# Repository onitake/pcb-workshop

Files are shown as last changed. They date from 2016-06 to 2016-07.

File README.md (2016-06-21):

PCB layouting workshop
======================

These are the example files and a short presentation for an
introduction to printed circuit board layouting with KiCad.

The design is loosely based on [Larry Ogrodnek's nametag](http://analogmachines.com/p/nametag/build/),
with some modifications and enhancements.
There's both through-hole and SMD versions.
The THT version is designed for 5mm LEDs, thus making it very
large. A new 3mm version is being worked on.

The software for the microcontroller is in [a separate project](https://github.com/nuess0r/am-nametag).

You can also find an example for a LED dot matrix display tag.
(currently broken, the pinout is wrong)

Description
-----------

The circuit is grouped in 4 parts:
- 5 LED blocks
- Transistor drivers for each block (based on 2N7002 N-FETs)
- ATtiny13 microcontoller
- CR2032 battery

Each block consists of a total of 20 LEDs in parallel, which can be
soldered on as desired.

It should be noted that the CR2032 has a high internal resistance
and can only deliver small currents, up to about 40mA.

The current-limiting resistors for each block should thus be
adjusted accordingly, to prevent brown-out of the MCU.
Note that the transistors also have a relatively high
on resistance.

If a Li-Ion or LiPo battery is used instead of the button
cell, much higher currents are possible.

The parts are fairly standard and can be ordered from any
supplier, such as Farnell, DigiKey, Reichelt, ...

License
-------

This documentation is copyright © 2016 by Chaostreff Basel and
describes Open Hardware and is licensed under the CERN OHL v. 1.2.
Please see the the [LICENSE](LICENSE) file for applicable conditions.

The author's contact information can be found in [AUTHORS](AUTHORS).

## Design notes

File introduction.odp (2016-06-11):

## KiCad

Introduction to Printed Circuit Board design

with KiCad 4.0

CoSin 2016

Gregor Riepl

## About KiCad

- PCB CAD Tool
- Open Source (GPL 3)
- Multiplatform (Windows, OSX, Linux, *BSD, …)
- Started in 1992
- Officially endorsed by CERN
- Many professional features
- Suitable for very simple and very complex projects

## Overview

- kicad
- eeschema
- cvpcb
- pcbnew
- gerbview
- pcb calculator
- part editor
- footprint editor

## kicad

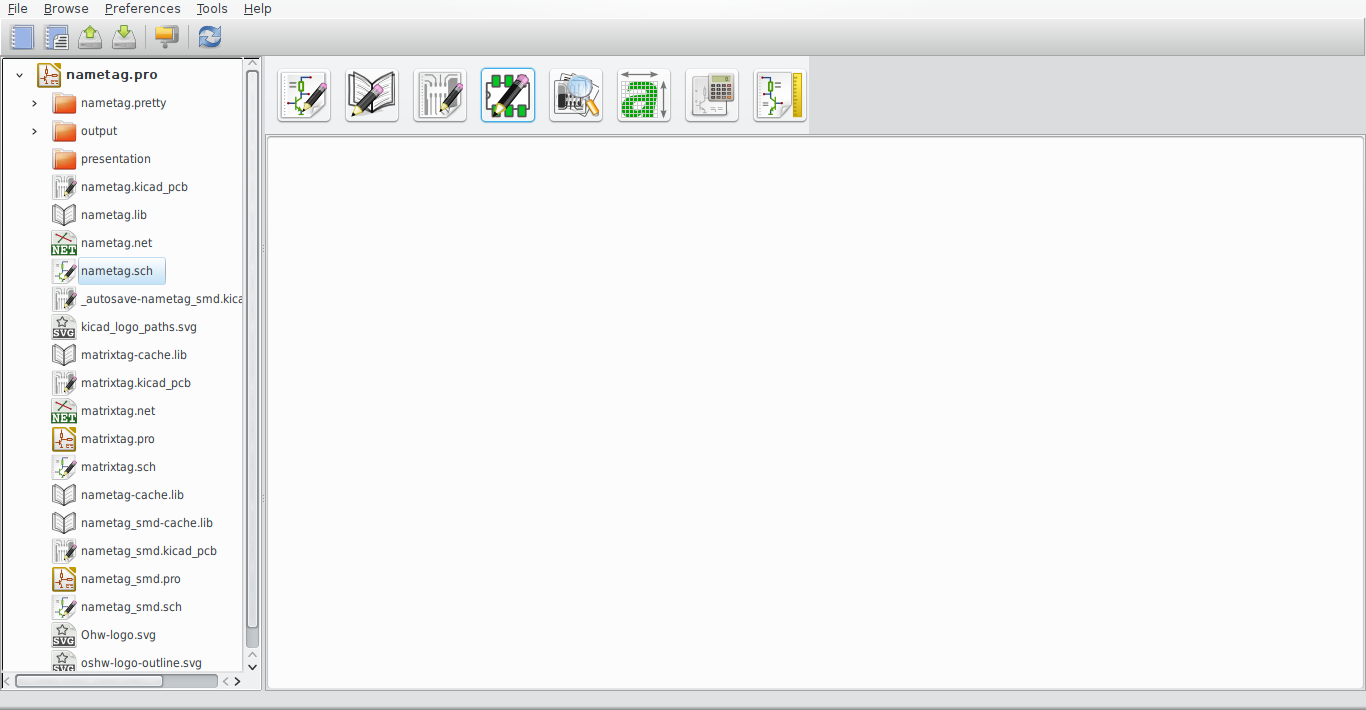
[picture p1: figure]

## eeschema

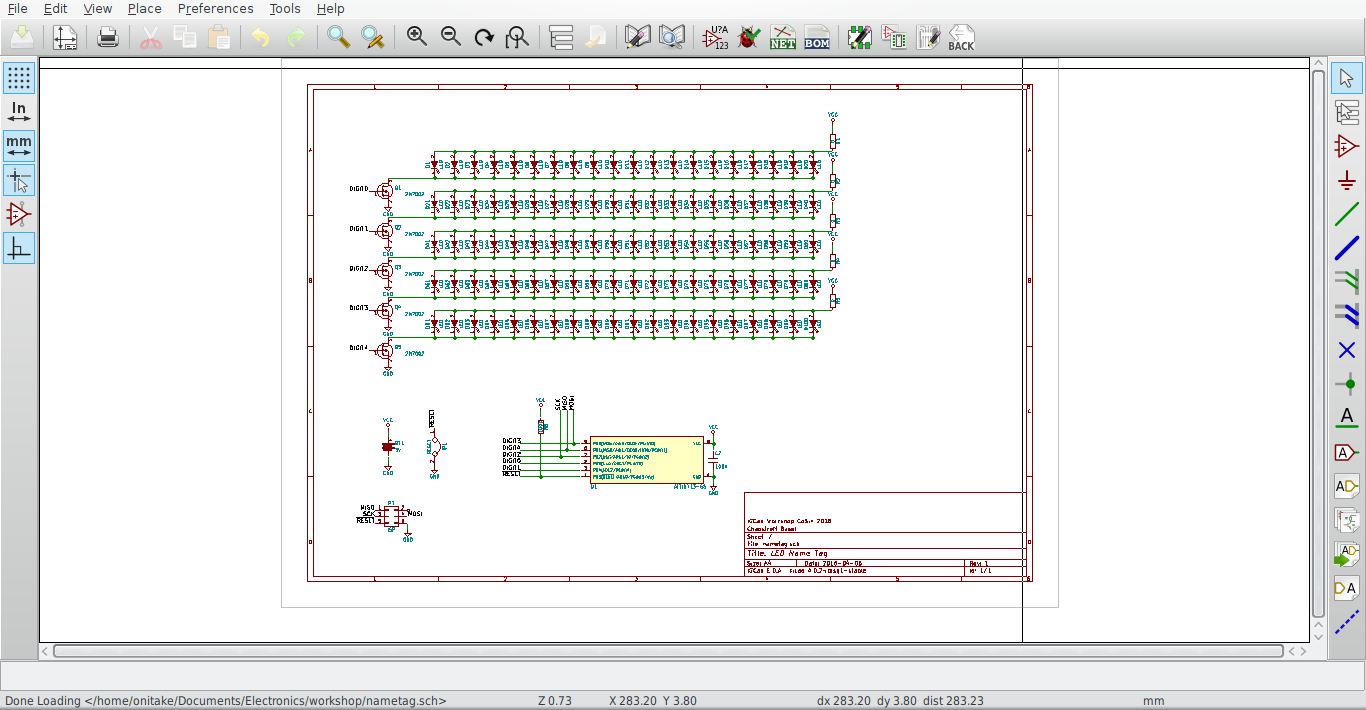
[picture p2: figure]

## cvpcb

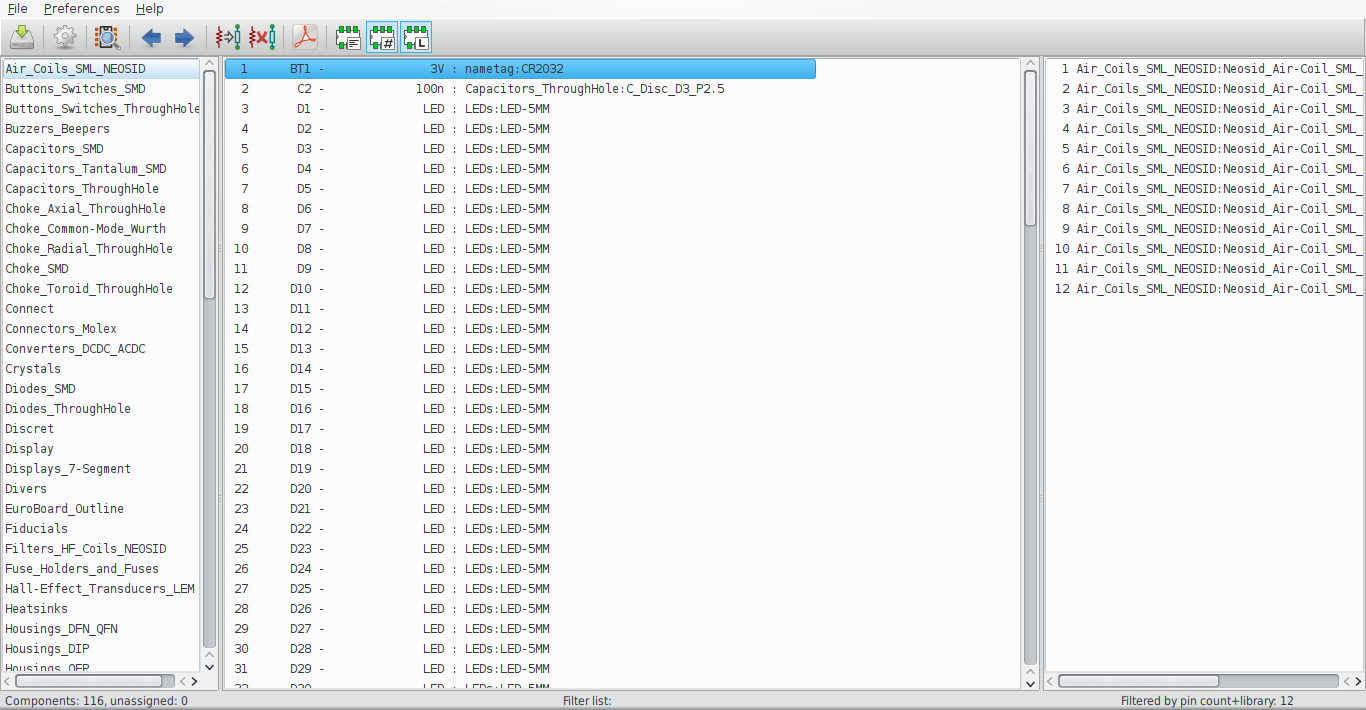
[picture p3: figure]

## pcbnew

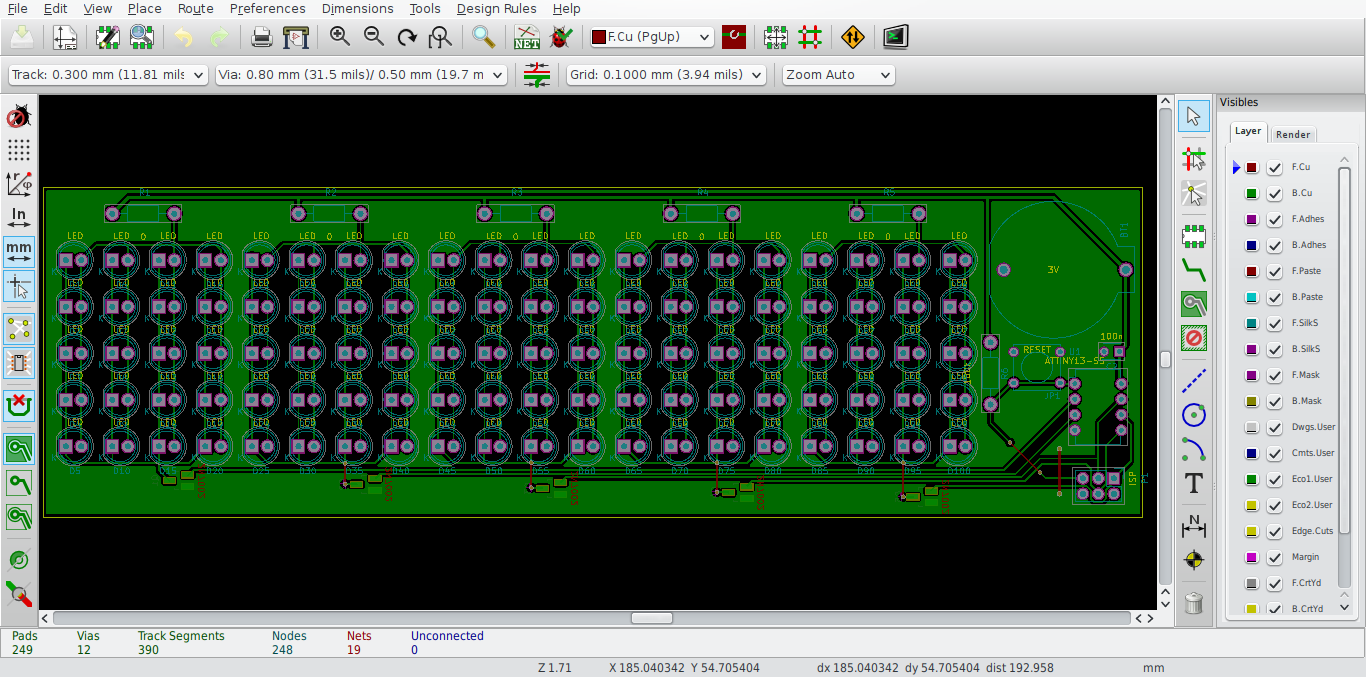
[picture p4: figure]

## gerbview

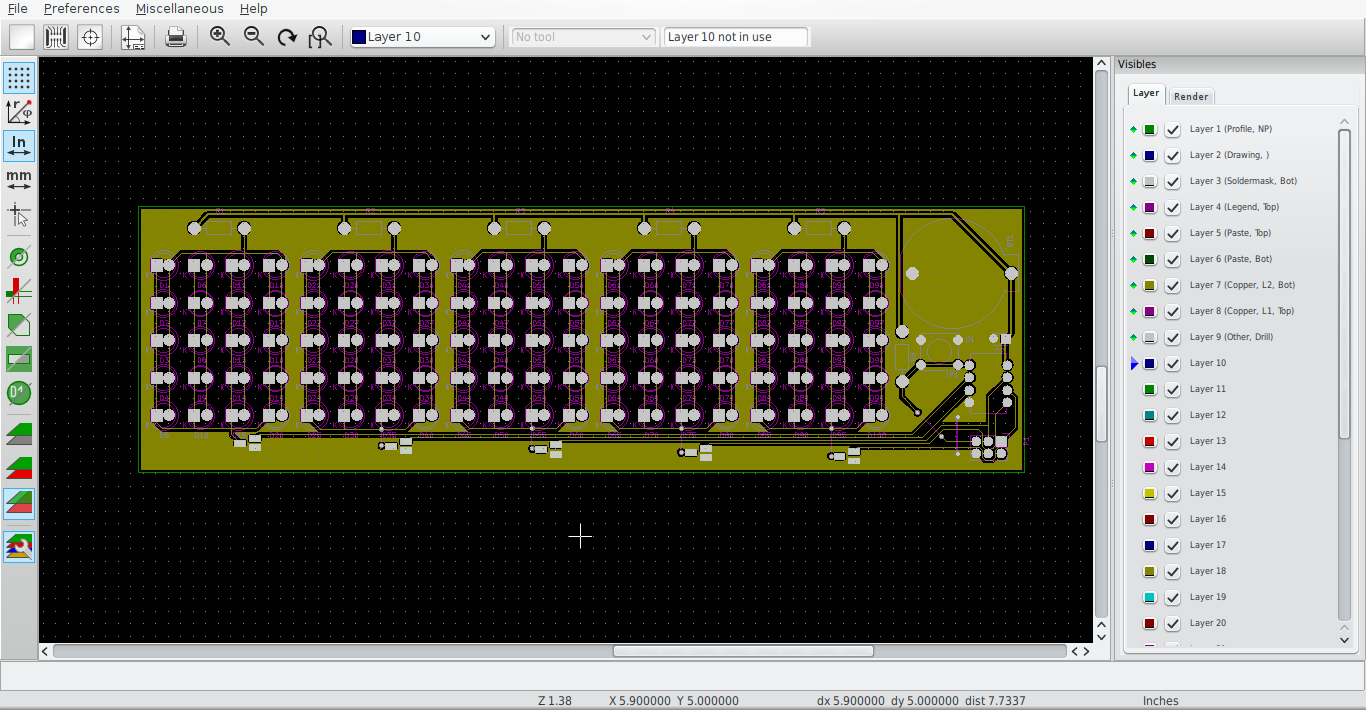
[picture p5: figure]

## part editor

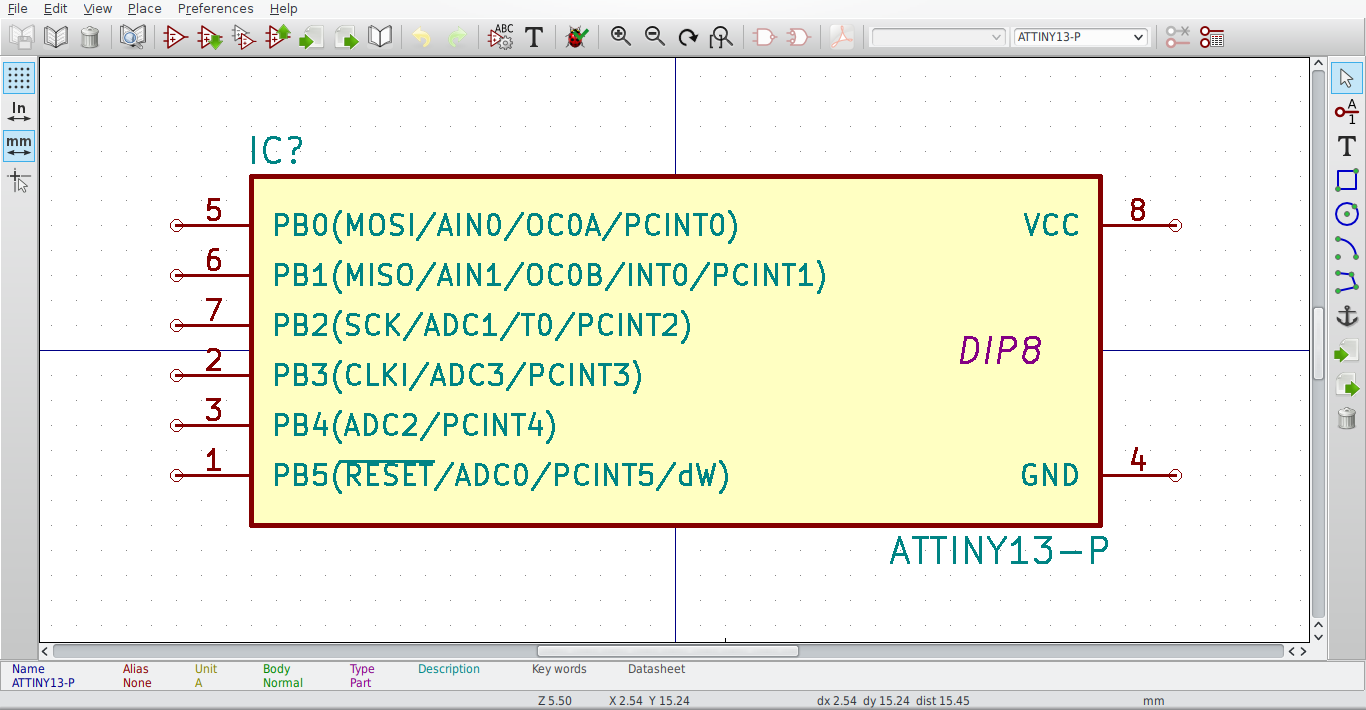
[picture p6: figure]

## footprint editor

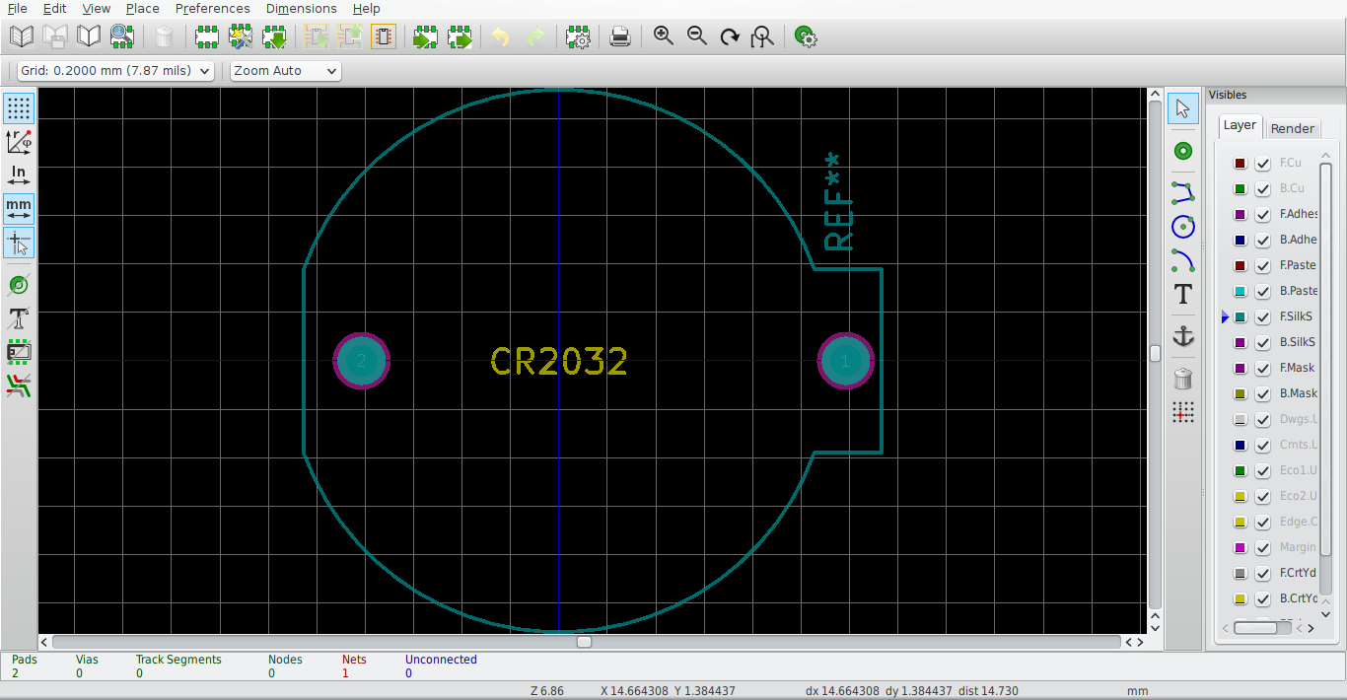
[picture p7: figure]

## Workflow

- Schema design
- Footprint assignment
- Netlist export / import
- PCB design
- Gerber / PDF export
- Verification
- Production

## Schema design

- Layout decision
- Part sourcing
- Part design / editing / library import
- Part placement
- Tracing / labeling
- Fine tuning
- Annotation
- ERC

## Parts

- KiCad has a large part library
- kicadlib.org has many more
- Creating custom parts is easy

## Netlists

- netlists = interface between eeschema and pcbnew
- Export after schema is complete
- Then import into pcbnew
- Backward annotation is not possible

## PCB design

- Design rules / Net classes
- Layout decision / edge cuts
- Part placement
- Power / ground planes
- Routing
- DRC

## Output

- Use Gerber for CAM
- Use PDF for DIY
- Each layer is a separate file
- Gerber layers can be checked in gerbview
- PDF export best mirrored, better exposure (focus)

## Questions?

- Answers!

## More

- http://kicad-pcb.org
- http://press.cern/press-releases/2011/07/cern-launches-open-hardware-initiative
- http://www.kicadlib.org/
- https://github.com/onitake/pcb-workshop

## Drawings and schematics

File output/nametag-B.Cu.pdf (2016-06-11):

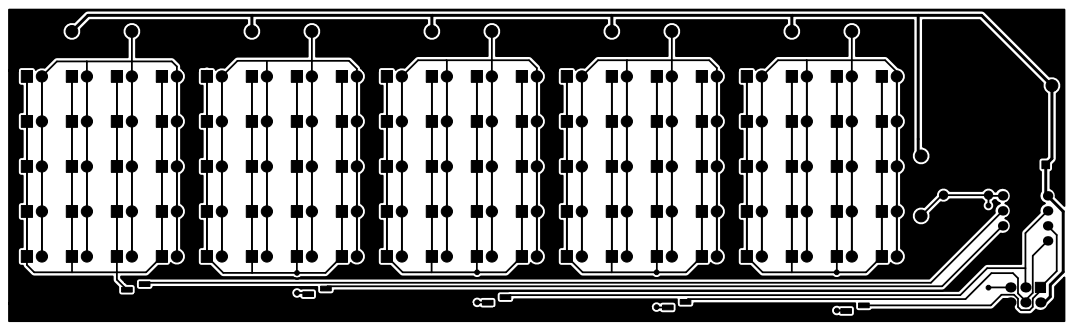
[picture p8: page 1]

File: nametag.kicad_pcb Sheet: Chaostreff Basel KiCad Workshop CoSin 2016

Id: 1/1 Title: LED Name Tag

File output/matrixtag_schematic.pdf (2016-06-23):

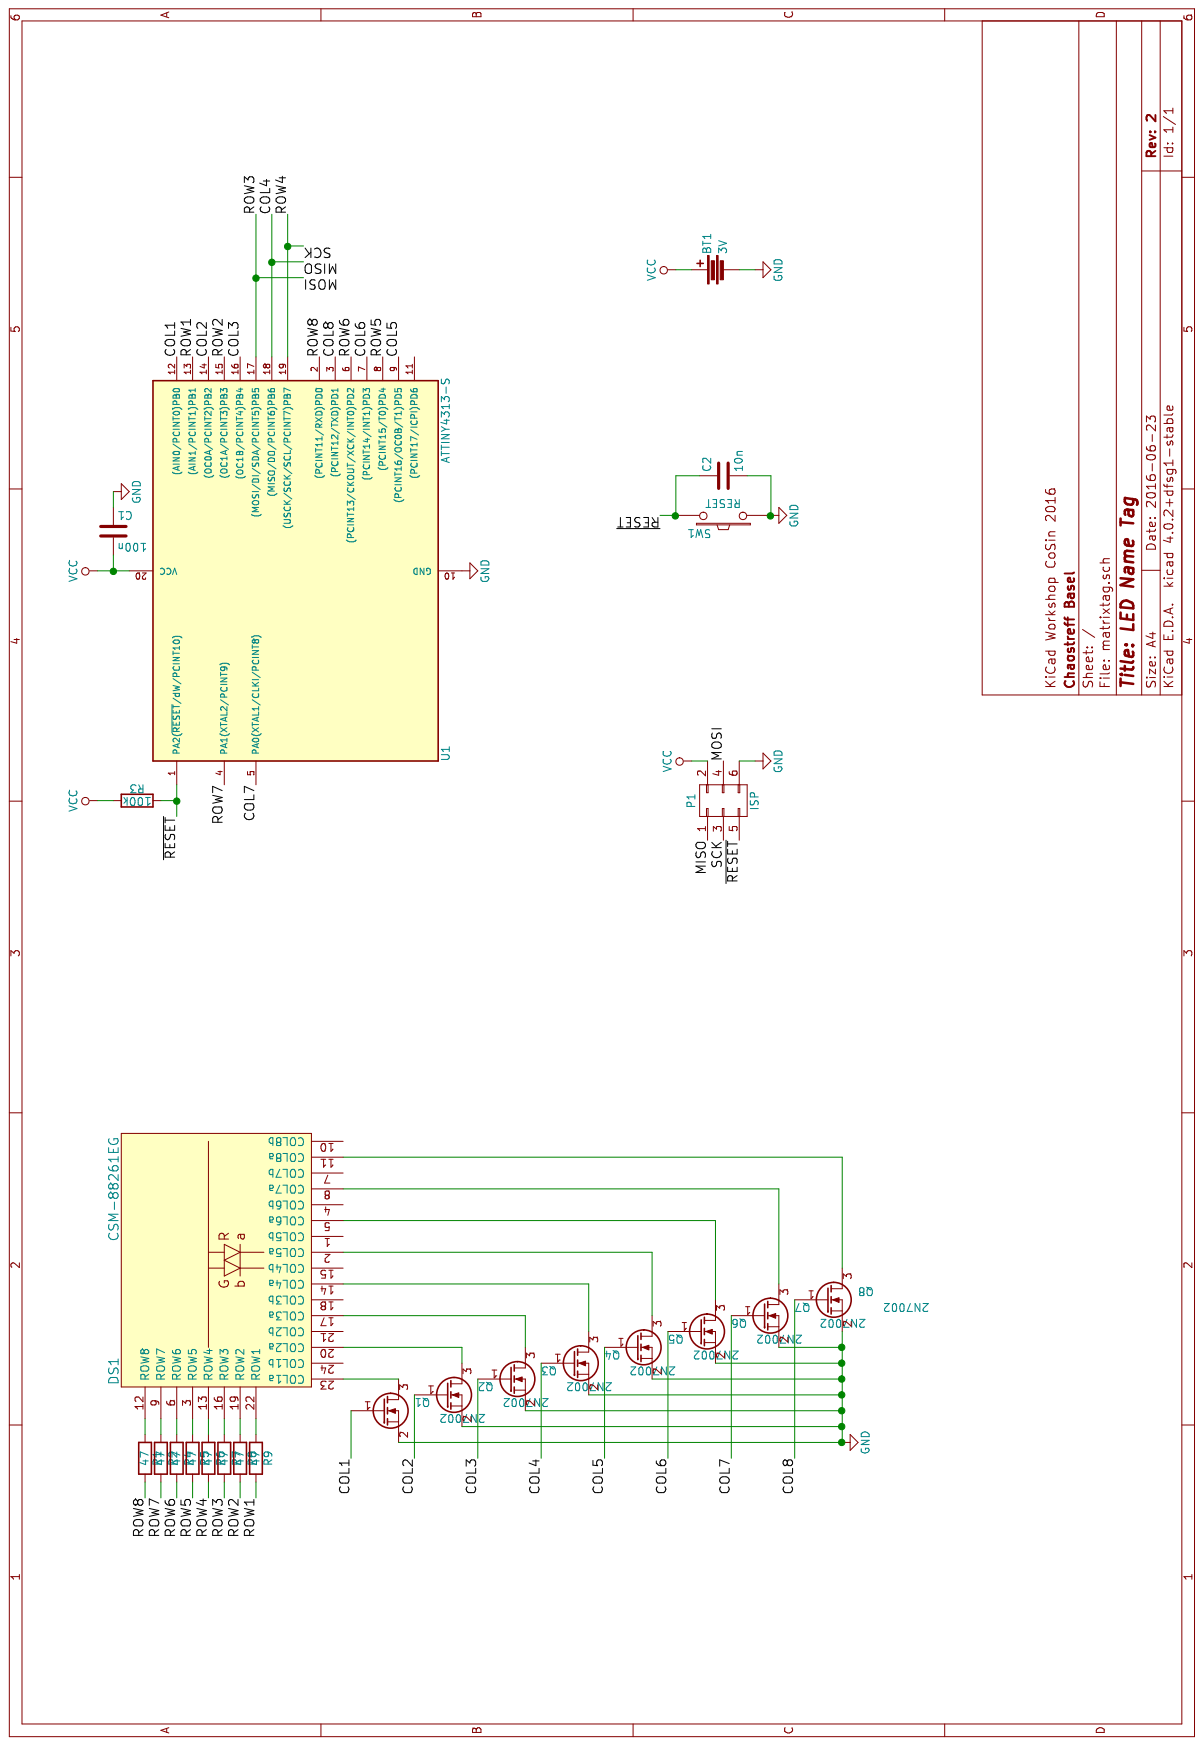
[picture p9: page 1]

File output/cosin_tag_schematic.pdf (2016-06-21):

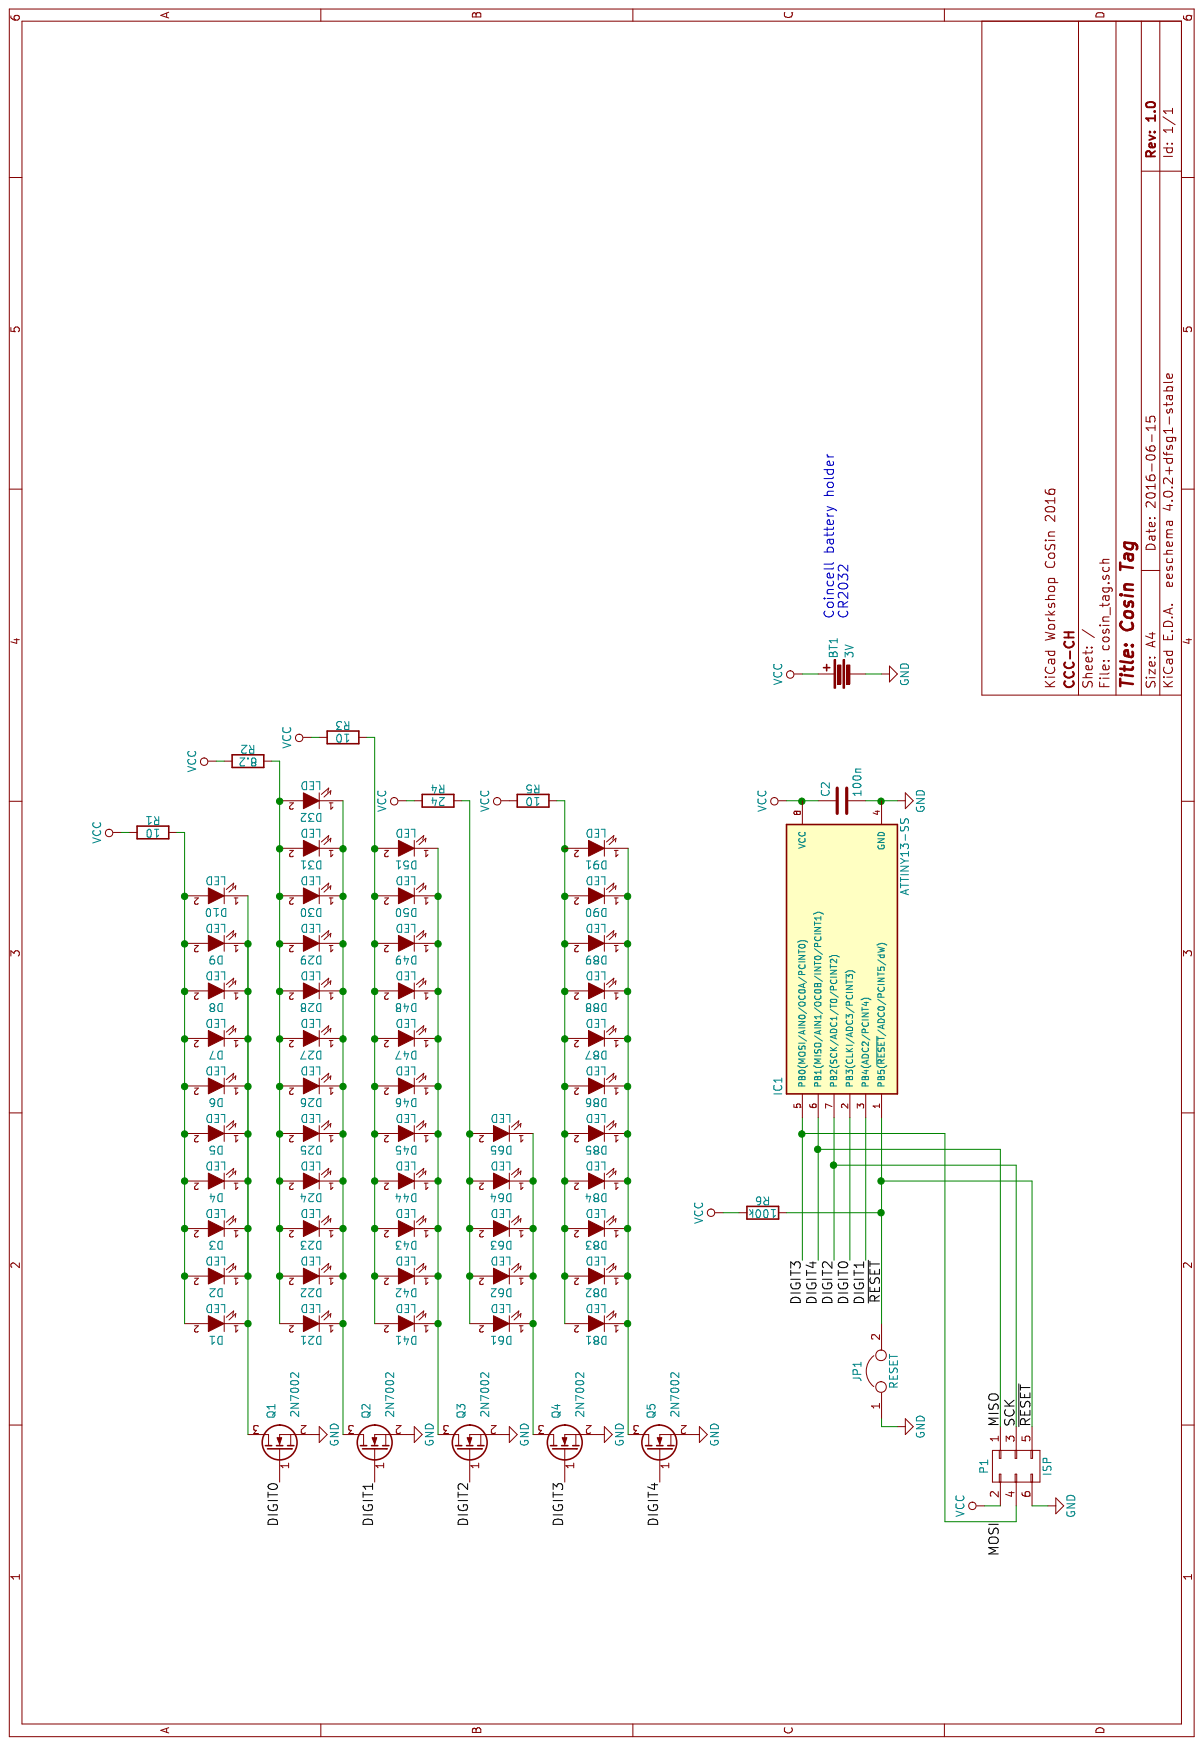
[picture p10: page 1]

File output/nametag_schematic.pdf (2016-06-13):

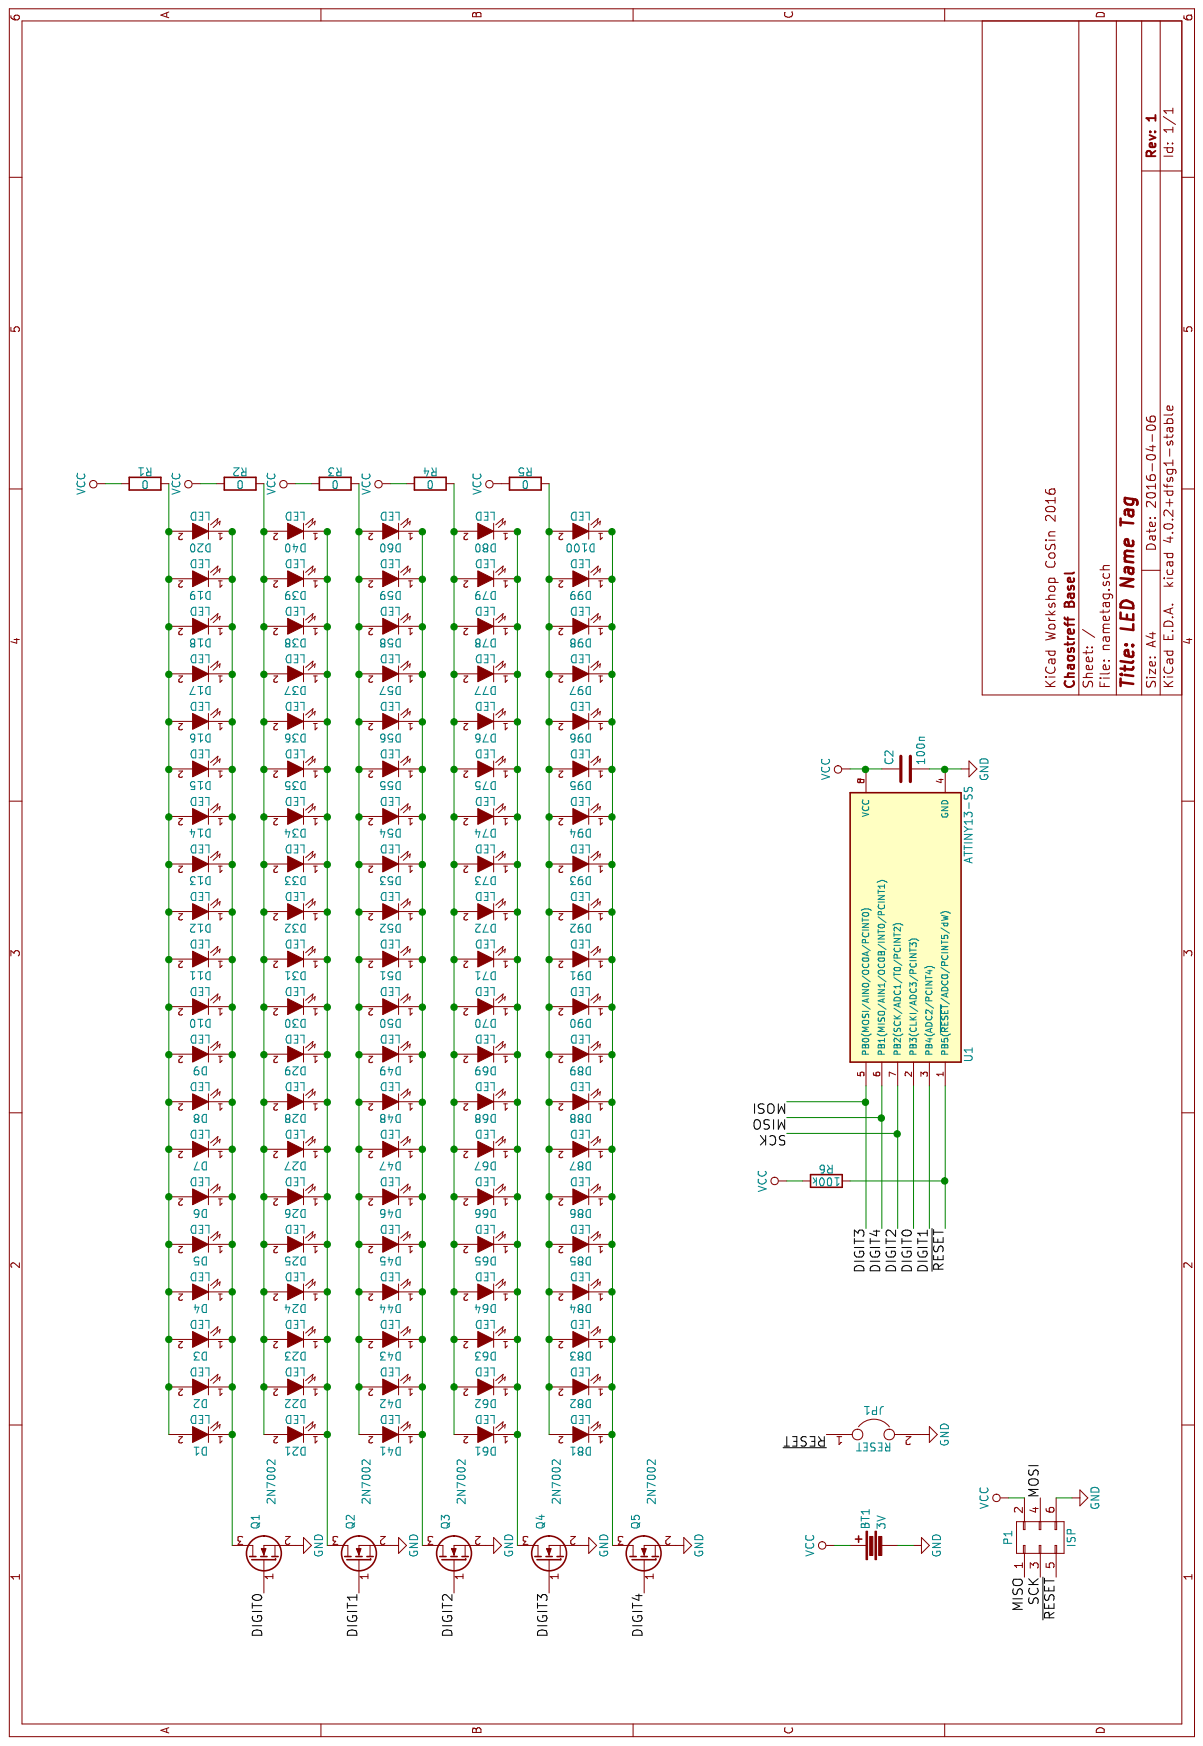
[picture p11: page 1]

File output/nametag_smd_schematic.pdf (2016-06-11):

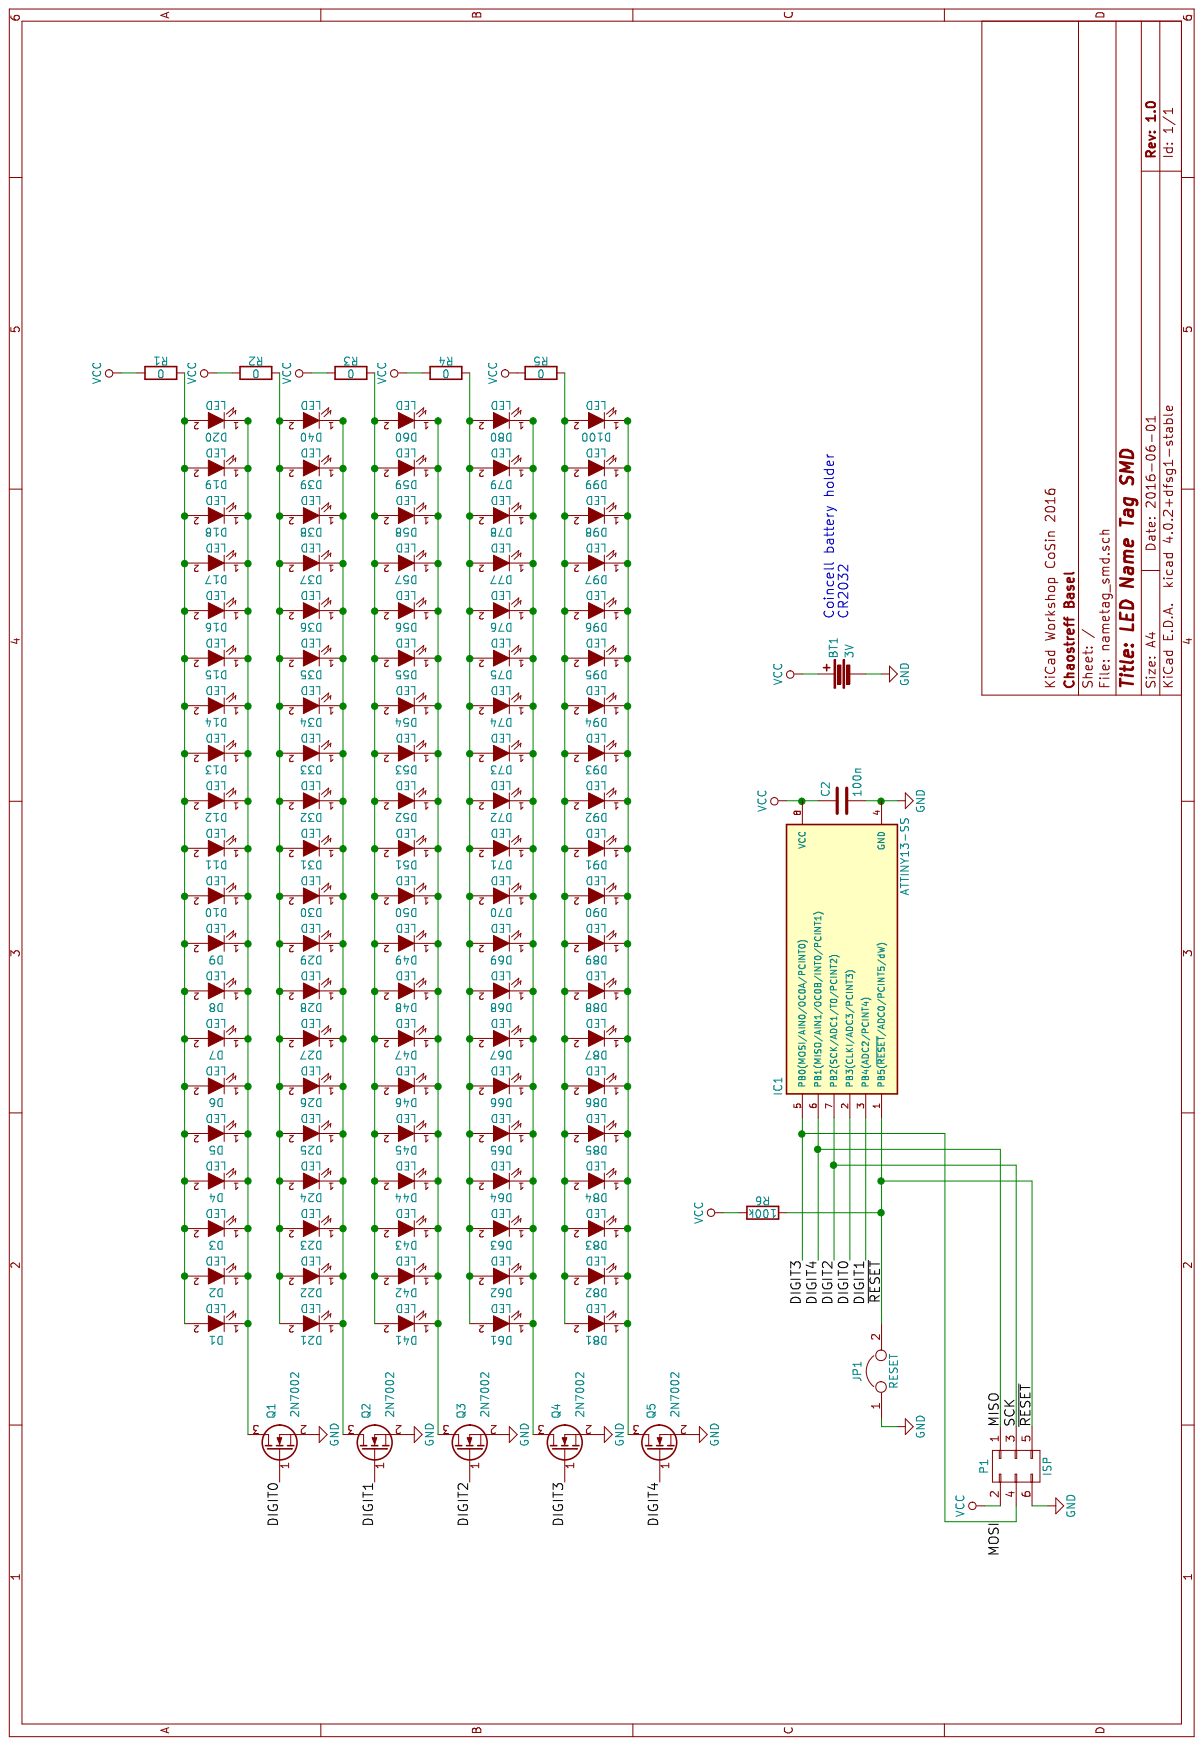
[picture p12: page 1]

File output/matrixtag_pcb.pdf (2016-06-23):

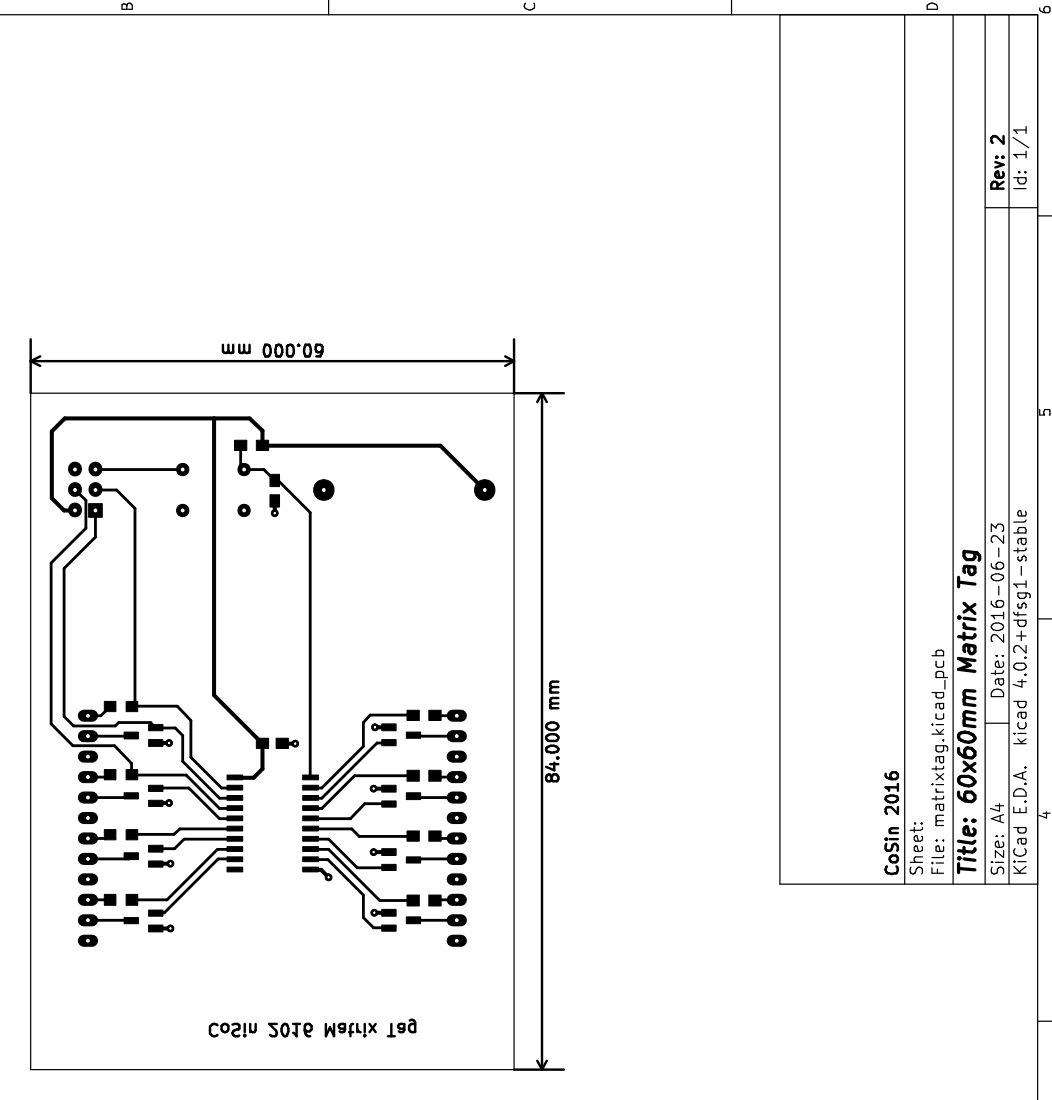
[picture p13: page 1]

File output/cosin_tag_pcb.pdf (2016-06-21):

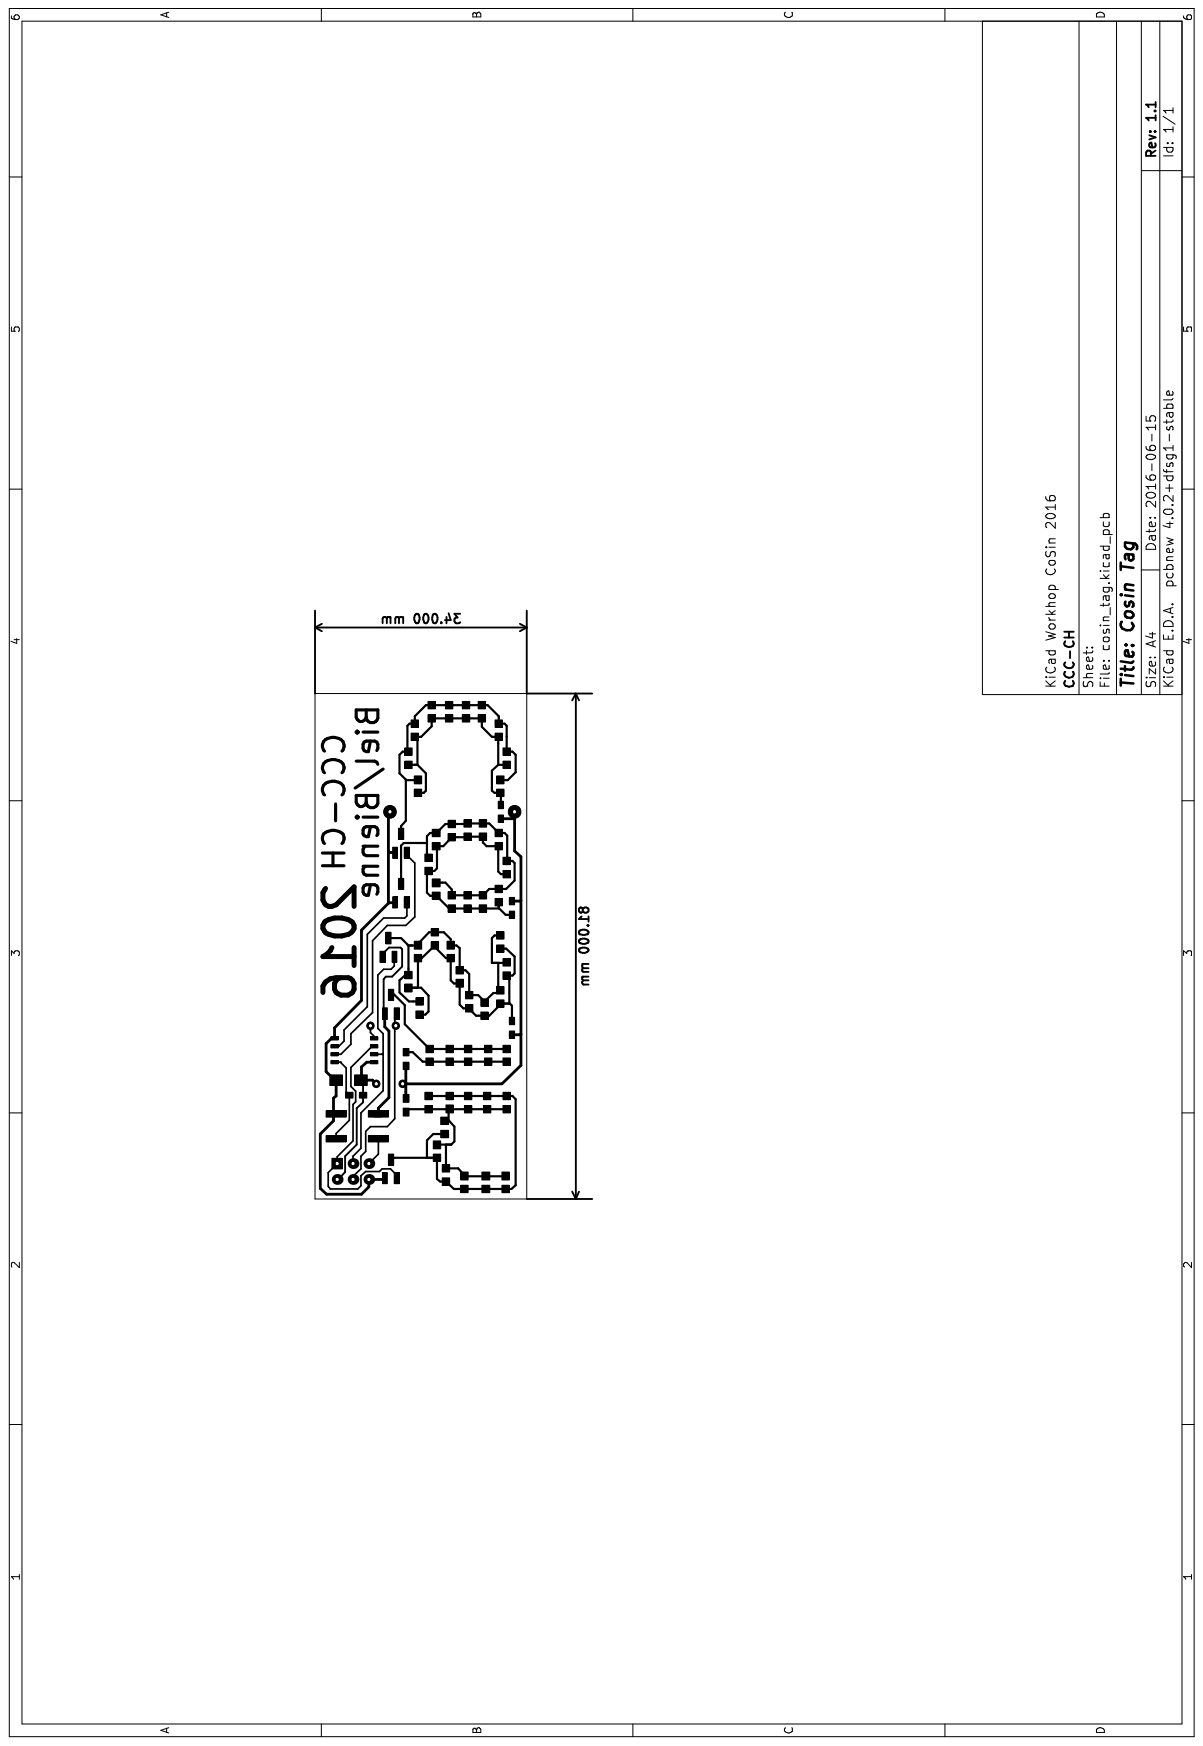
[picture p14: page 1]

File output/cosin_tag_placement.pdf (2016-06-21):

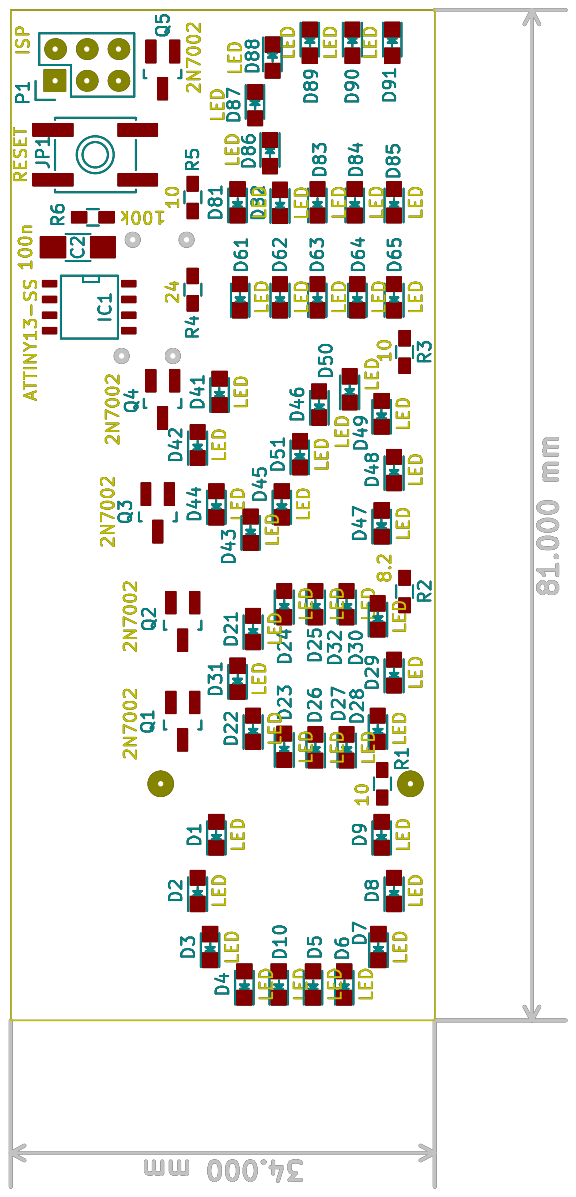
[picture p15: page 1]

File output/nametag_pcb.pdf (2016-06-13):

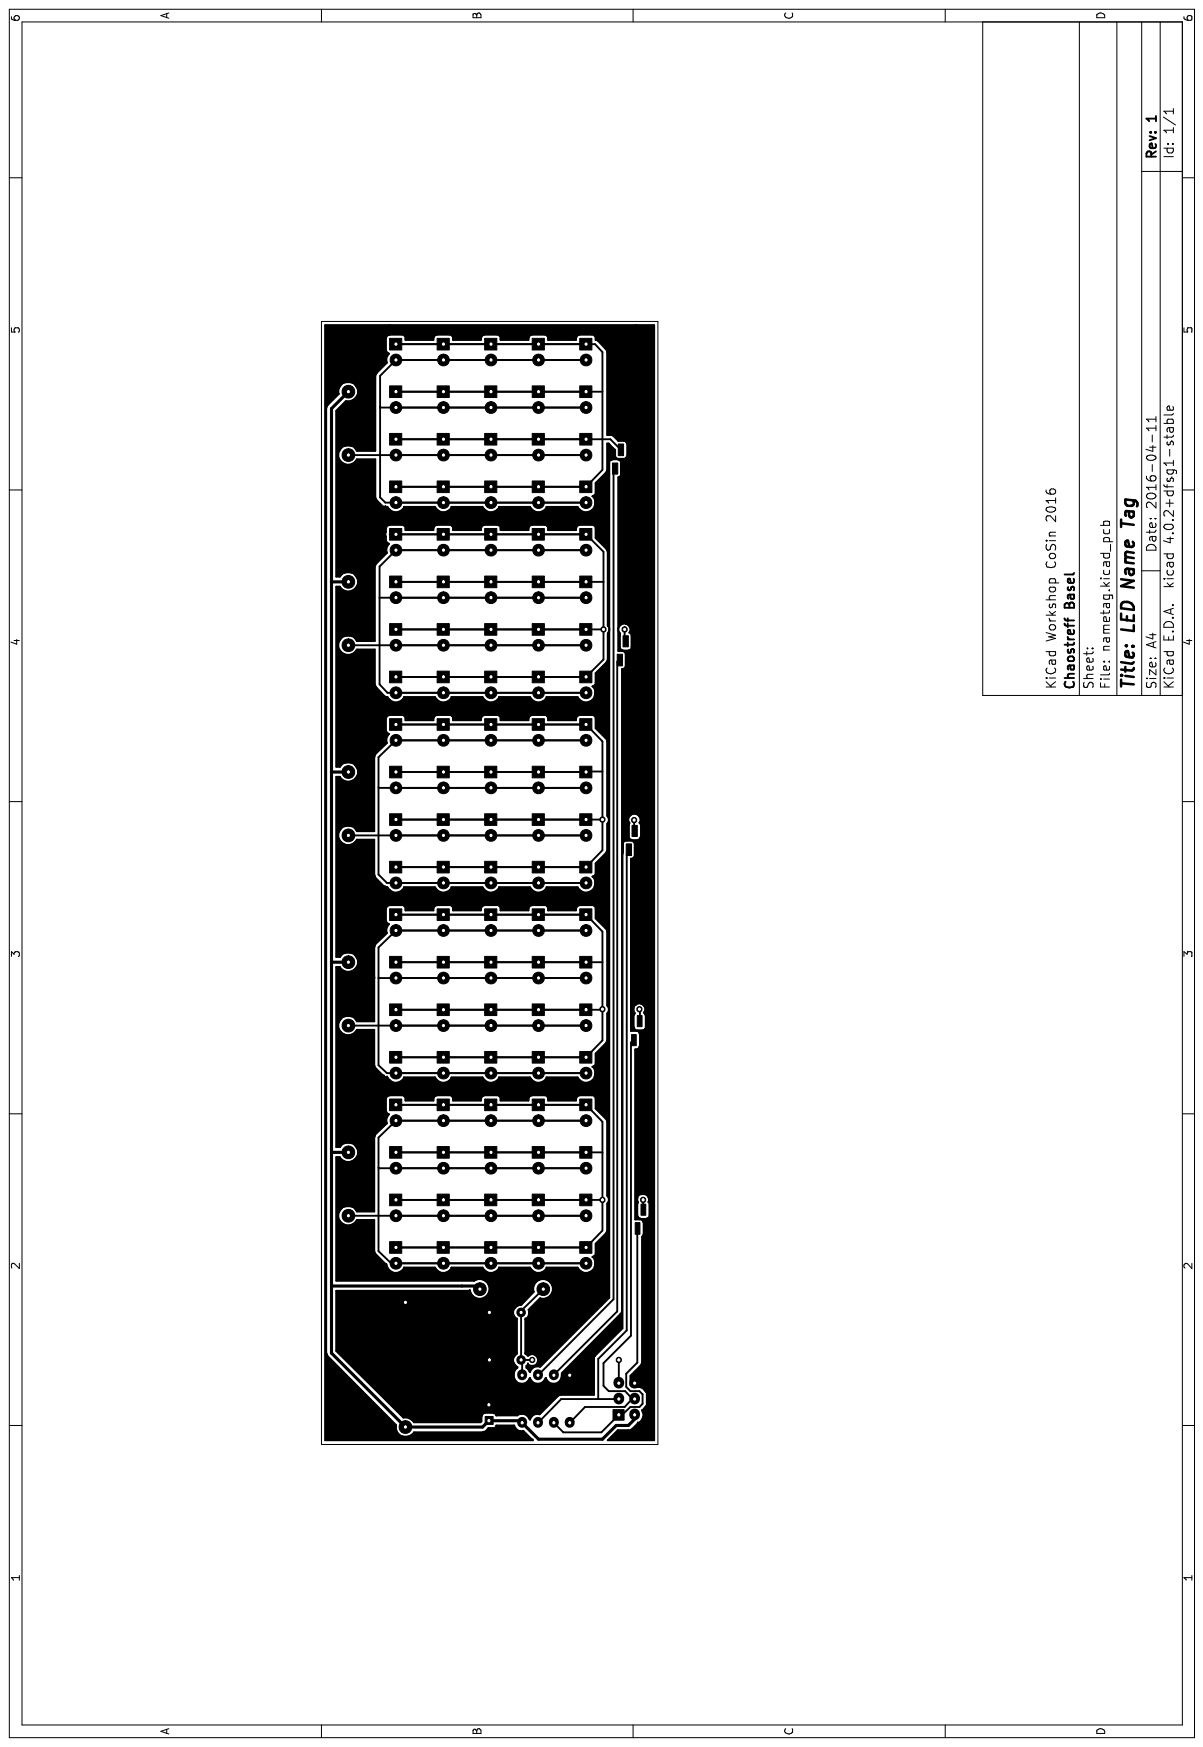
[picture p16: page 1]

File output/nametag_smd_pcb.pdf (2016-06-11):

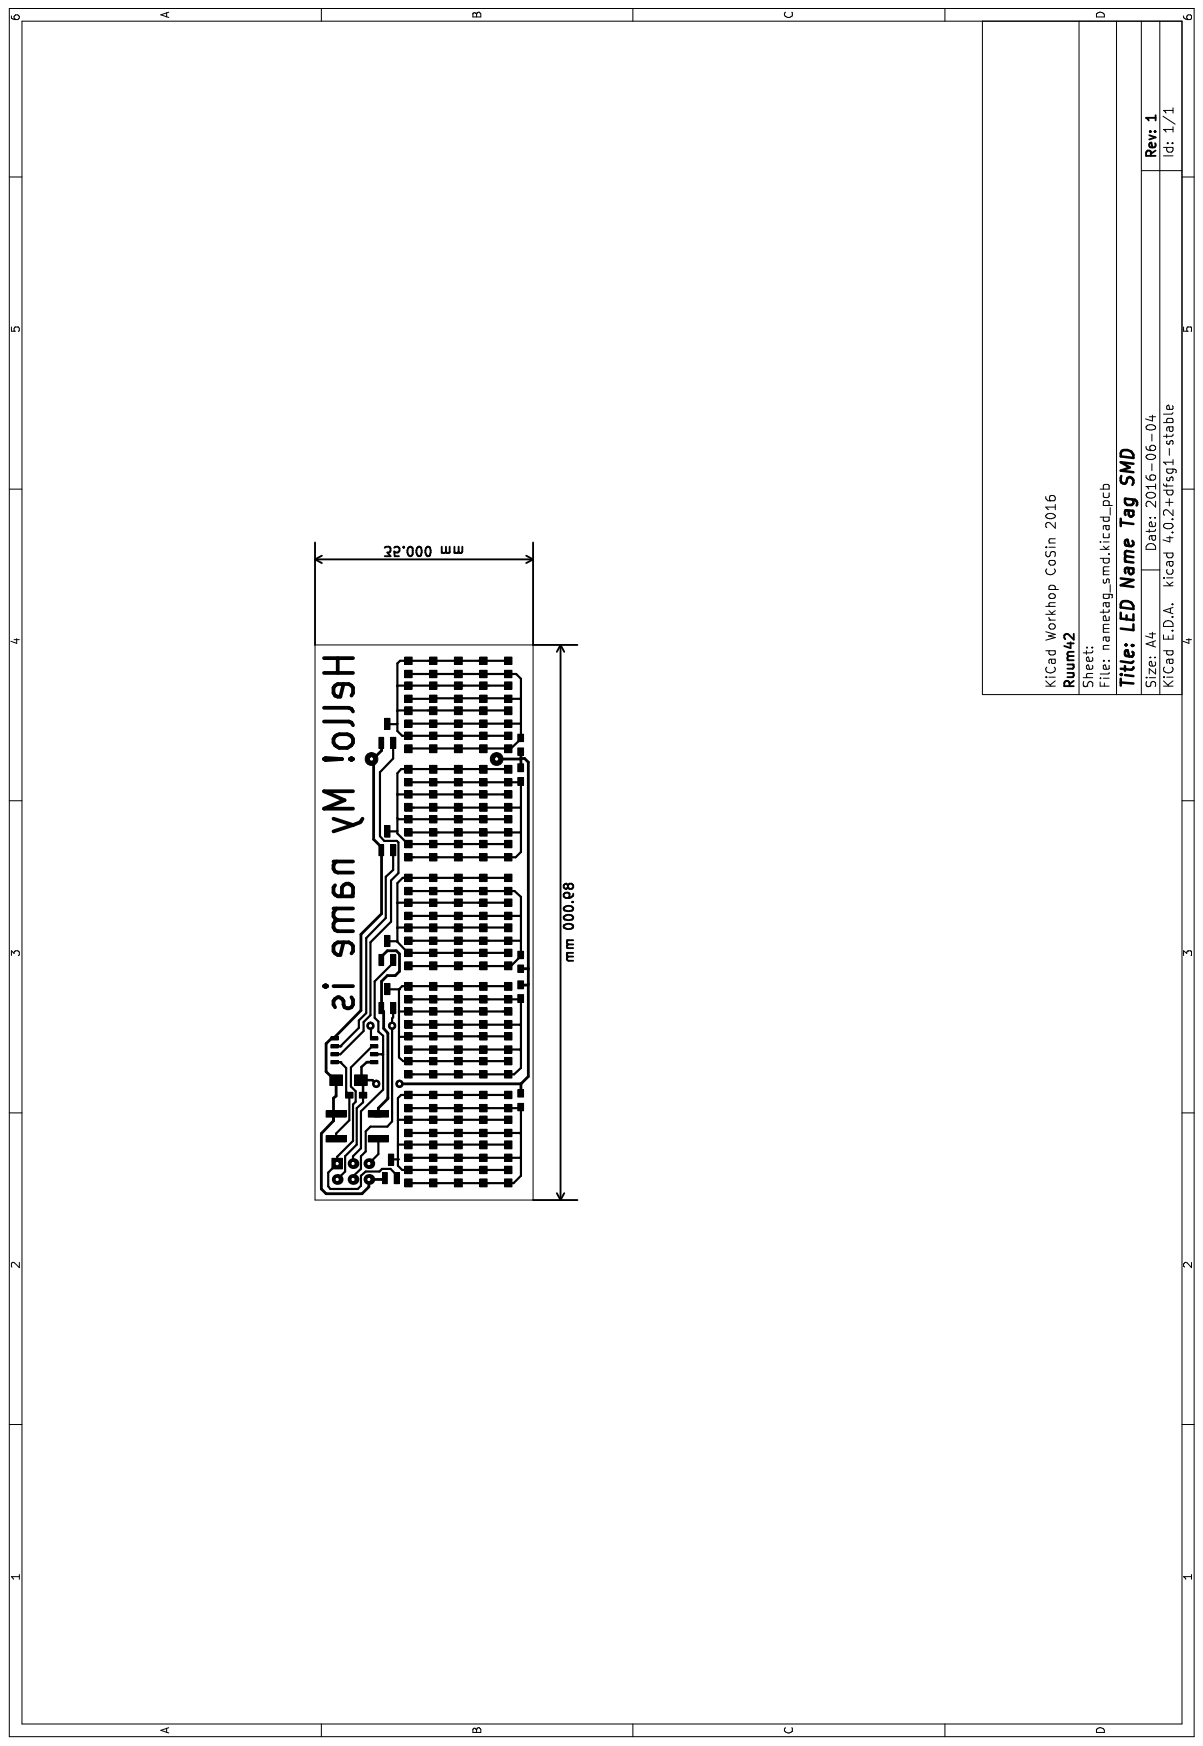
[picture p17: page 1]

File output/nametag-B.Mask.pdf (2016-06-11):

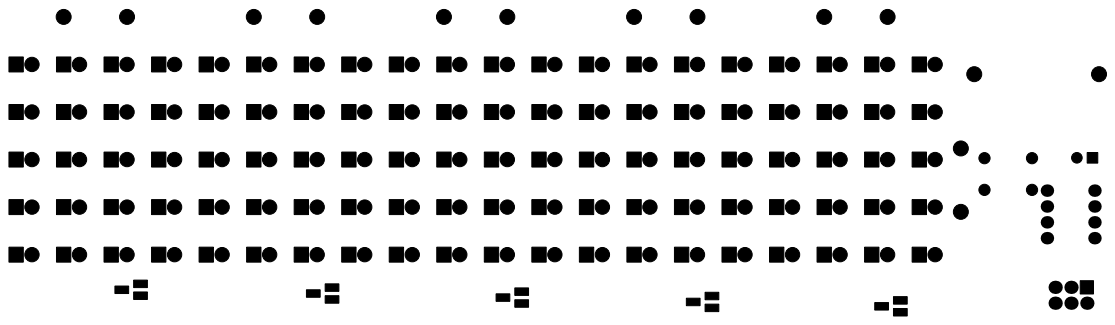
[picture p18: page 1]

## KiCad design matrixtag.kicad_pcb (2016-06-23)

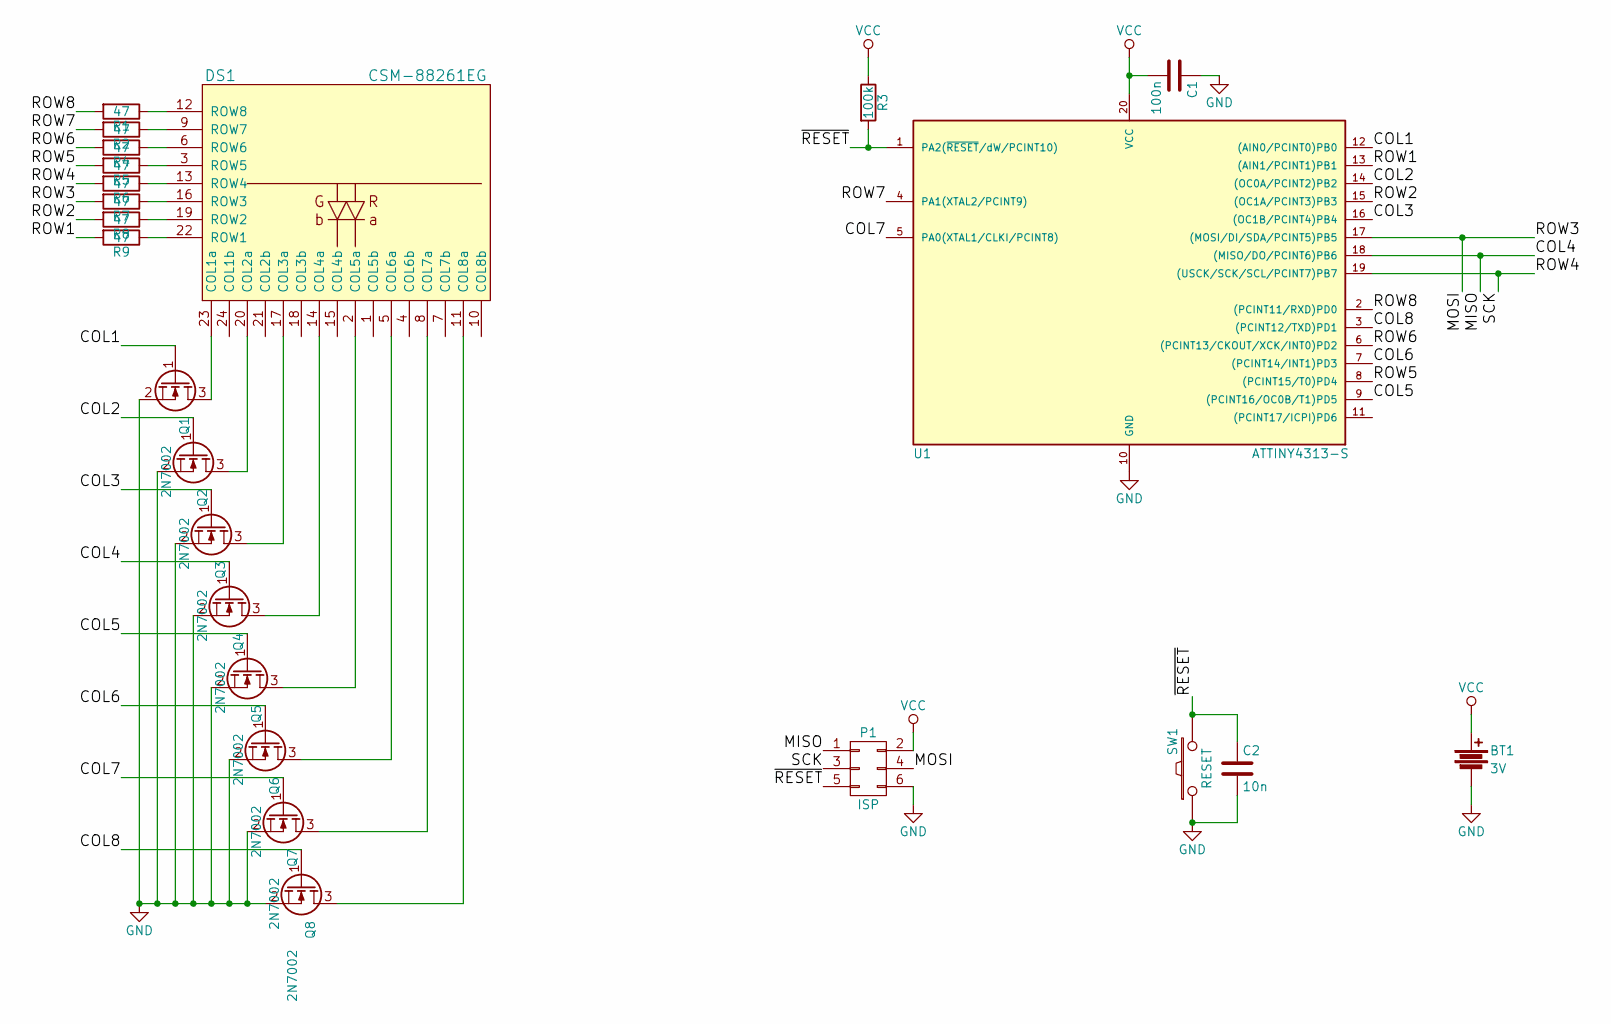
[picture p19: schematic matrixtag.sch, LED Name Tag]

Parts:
BT1: 3V; CR2032
C1: 100n; C_0805_HandSoldering
C2: 10n; C_0805_HandSoldering
DS1: CSM-88261EG; CSM-88261
P1: ISP; Pin_Header_Straight_2x03
Q1, Q2, Q3, Q4, Q5, Q6, Q7, Q8: 2N7002; SOT-23_Handsoldering
R1, R2, R4, R5, R6, R7, R8, R9: 47; R_0805_HandSoldering
R3: 100k; R_0805_HandSoldering
SW1: RESET; SW_PUSH_SMALL
U1: ATTINY4313-S; SOIC-20_7.5x12.8mm_Pitch1.27mm

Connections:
/COL1: Q1.1 (G), U1.12 ((AIN0/PCINT0)PB0)
/COL2: Q2.1 (G), U1.14 ((OC0A/PCINT2)PB2)
/COL3: Q3.1 (G), U1.16 ((OC1B/PCINT4)PB4)
/COL4: P1.1, Q4.1 (G), U1.18 ((MISO/DO/PCINT6)PB6)
/COL5: Q5.1 (G), U1.9 ((PCINT16/OC0B/T1)PD5)
/COL6: Q6.1 (G), U1.7 ((PCINT14/INT1)PD3)
/COL7: Q7.1 (G), U1.5 (PA0(XTAL1/CLKI/PCINT8))
/COL8: Q8.1 (G), U1.3 ((PCINT12/TXD)PD1)
/MOSI: P1.4, R7.2, U1.17 ((MOSI/DI/SDA/PCINT5)PB5)
/ROW1: R9.2, U1.13 ((AIN1/PCINT1)PB1)
/ROW2: R8.2, U1.15 ((OC1A/PCINT3)PB3)
/ROW4: P1.3, R6.2, U1.19 ((USCK/SCK/SCL/PCINT7)PB7)
/ROW5: R5.2, U1.8 ((PCINT15/T0)PD4)
/ROW6: R4.2, U1.6 ((PCINT13/CKOUT/XCK/INT0)PD2)
/ROW7: R2.2, U1.4 (PA1(XTAL2/PCINT9))
/ROW8: R1.2, U1.2 ((PCINT11/RXD)PD0)
/~RESET: C2.1, P1.5, R3.2, SW1.2, U1.1 (PA2(~RESET~/dW/PCINT10))
GND: BT1.2, C1.1, C2.2, P1.6, Q1.2 (S), Q2.2 (S), Q3.2 (S), Q4.2 (S), Q5.2 (S), Q6.2 (S), Q7.2 (S), Q8.2 (S), SW1.1, U1.10 (GND)
unnamed: DS1.2 (COL5a), Q5.3 (D)
unnamed: DS1.3 (ROW5), R5.1
unnamed: DS1.5 (COL6a), Q6.3 (D)
unnamed: DS1.6 (ROW6), R4.1
unnamed: DS1.8 (COL7a), Q7.3 (D)
unnamed: DS1.9 (ROW7), R2.1
unnamed: DS1.11 (COL8a), Q8.3 (D)
unnamed: DS1.12 (ROW8), R1.1
unnamed: DS1.13 (ROW4), R6.1
unnamed: DS1.14 (COL4a), Q4.3 (D)
unnamed: DS1.16 (ROW3), R7.1
unnamed: DS1.17 (COL3a), Q3.3 (D)
unnamed: DS1.19 (ROW2), R8.1
unnamed: DS1.20 (COL2a), Q2.3 (D)
unnamed: DS1.22 (ROW1), R9.1
unnamed: DS1.23 (COL1a), Q1.3 (D)
VCC: BT1.1, C1.2, P1.2, R3.1, U1.20 (VCC)

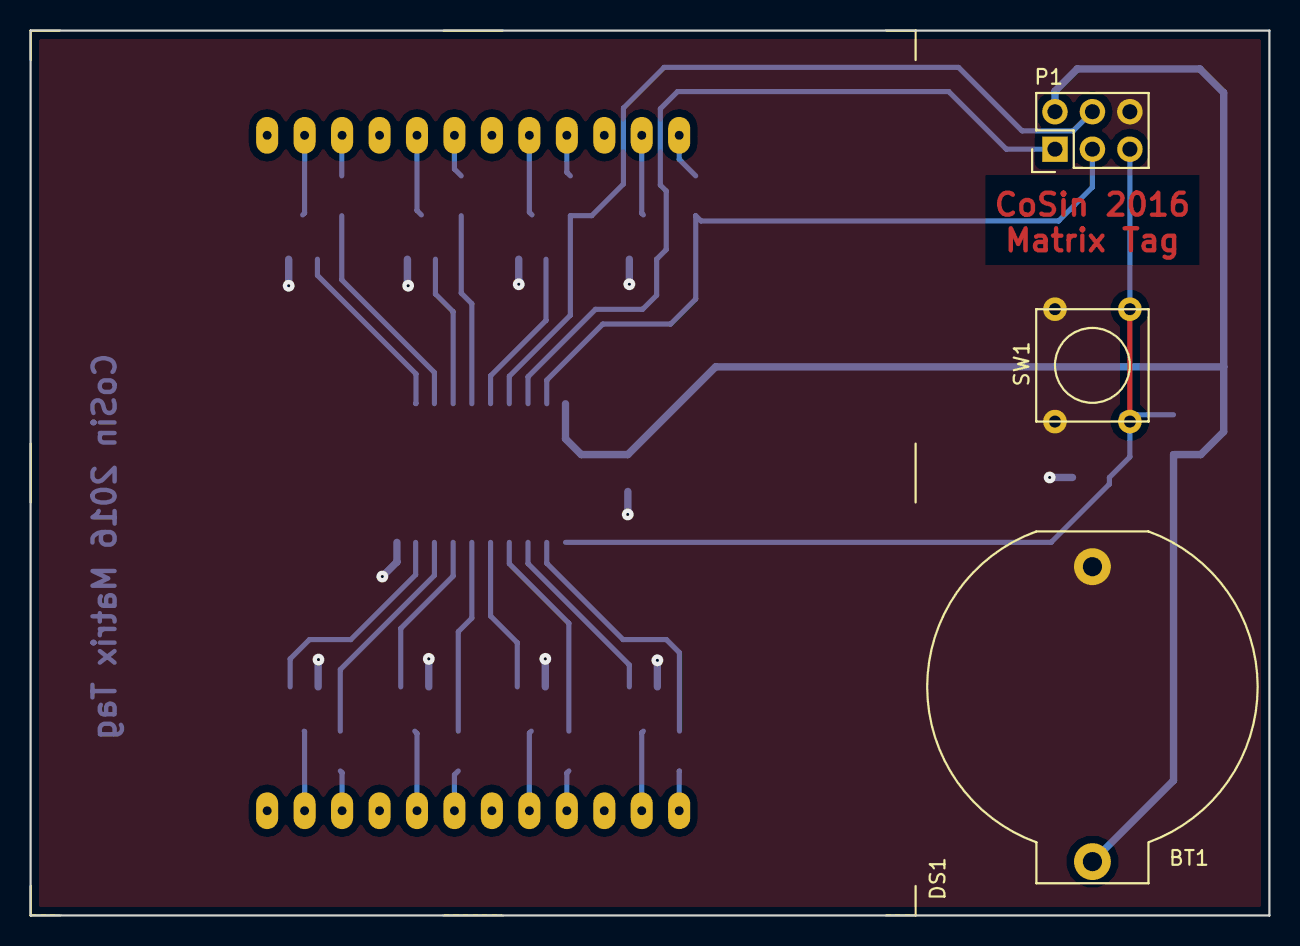
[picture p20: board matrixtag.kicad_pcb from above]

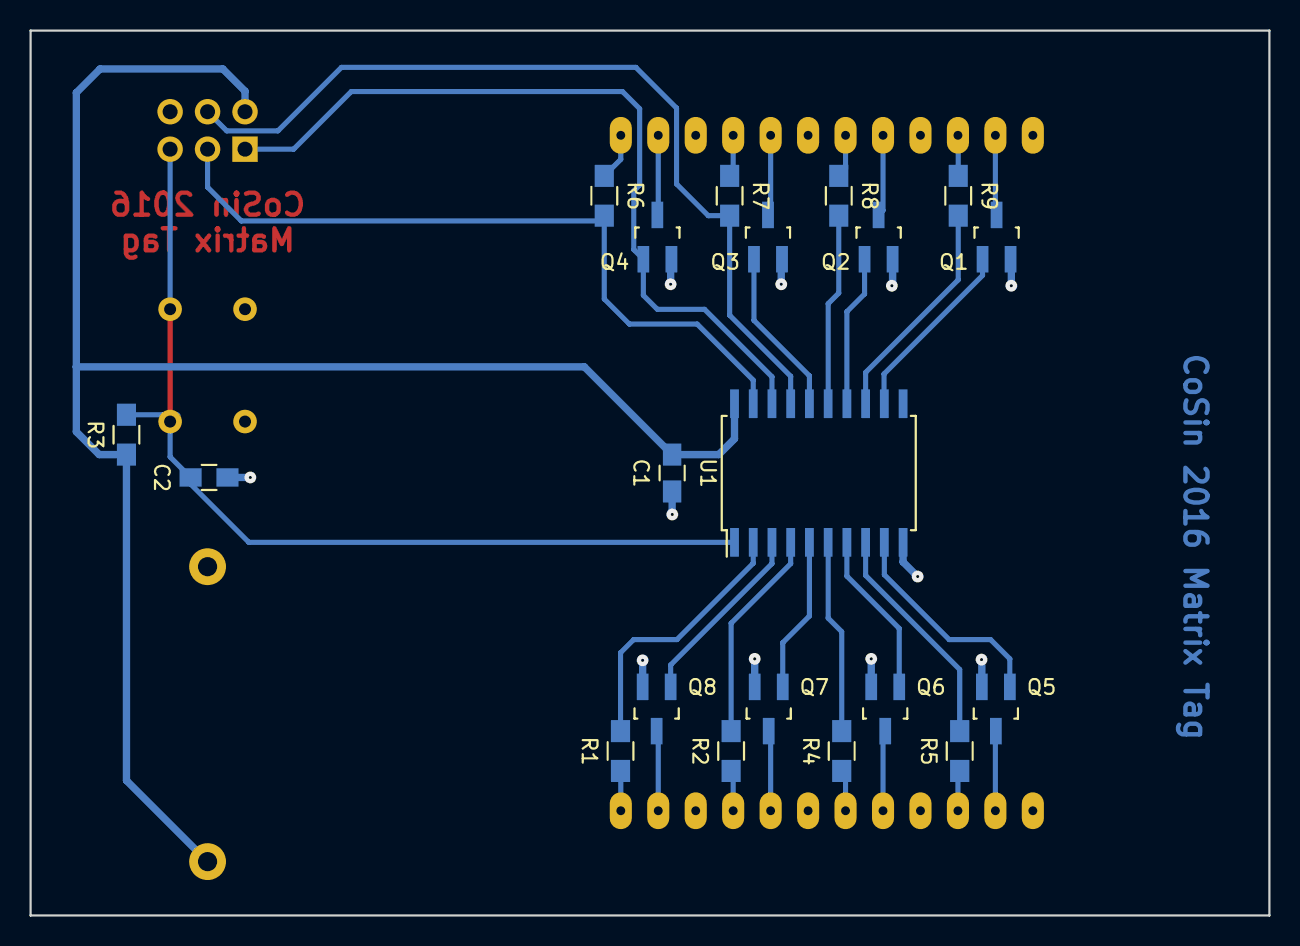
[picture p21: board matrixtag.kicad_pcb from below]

Board: 2 copper layers, 84.0 x 60.0 mm, 24 parts (20 on the bottom side), 35 nets.

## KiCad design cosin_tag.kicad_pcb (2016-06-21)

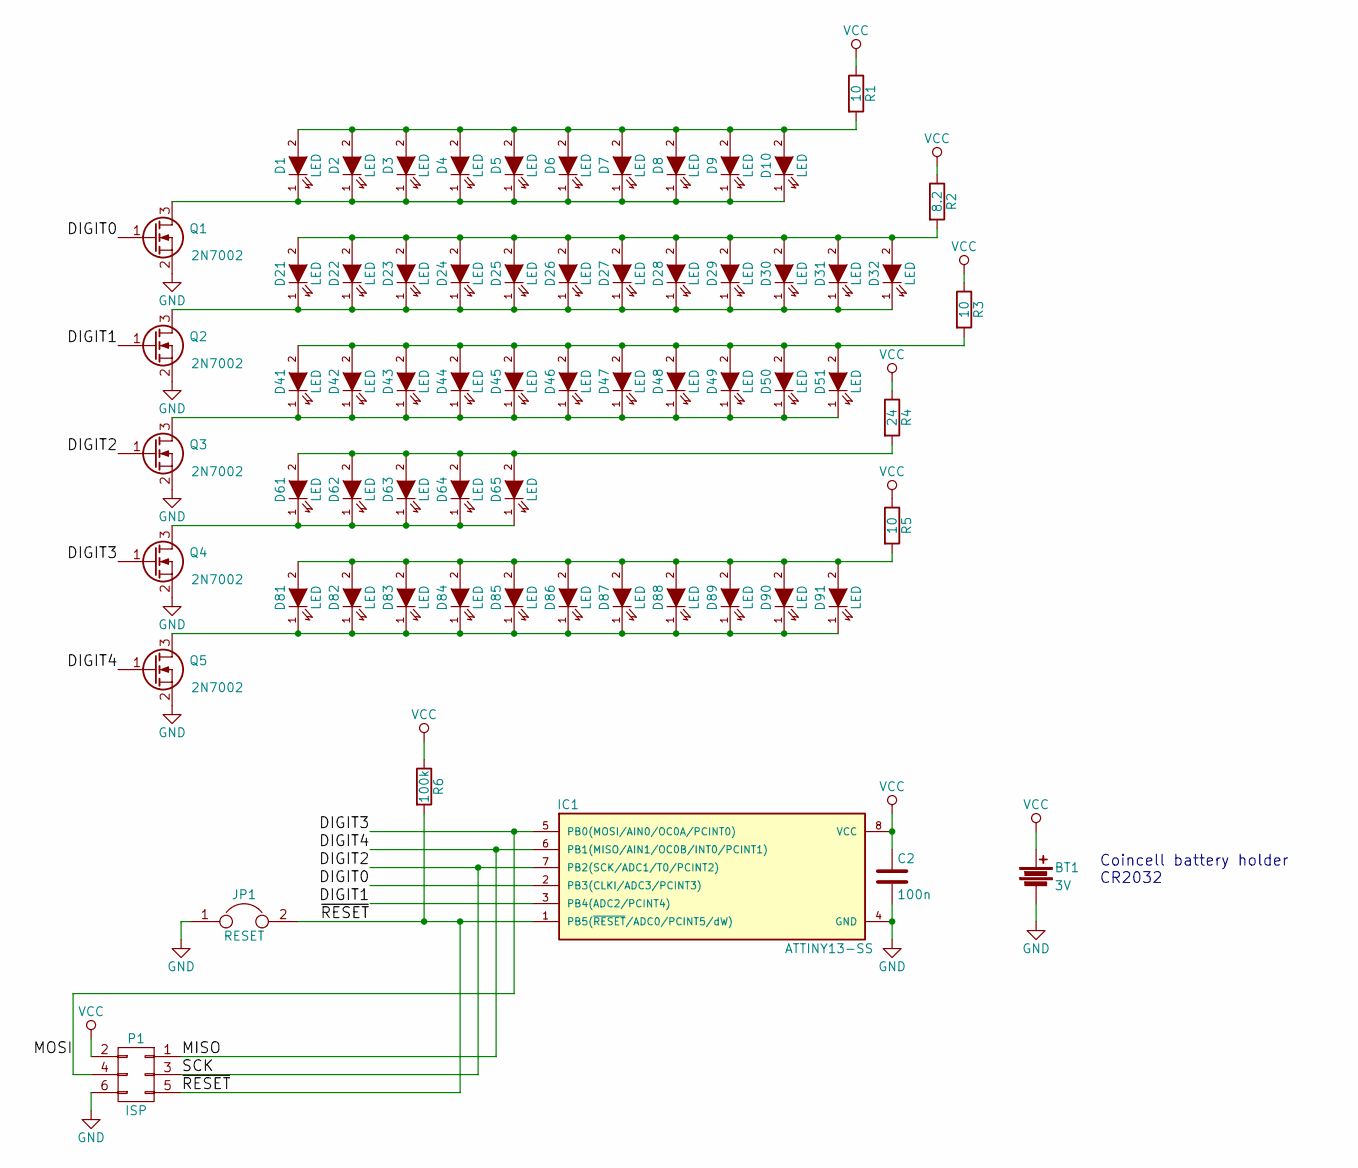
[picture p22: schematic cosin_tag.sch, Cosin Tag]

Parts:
BT1: 3V; CR2032
C2: 100n; R_1206_HandSoldering
D1, D2, D3, D4, D5, D6, D7, D8, D9, D10, D21, D22, D23, D24, D25, D26, D27, D28, D29, D30, D31, D32, D41, D42, D43, D44, D45, D46, D47, D48, D49, D50, D51, D61, D62, D63, D64, D65, D81, D82, D83, D84, D85, D86, D87, D88, D89, D90, D91: LED; LED_0805
IC1: ATTINY13-SS; SOIC-8-N
JP1: RESET; SW_SPST_EVQP0
P1: ISP; Pin_Header_Straight_2x03
Q1, Q2, Q3, Q4, Q5: 2N7002; SOT-23_Handsoldering
R1, R3, R5: 10; R_0603_HandSoldering
R2: 8.2; R_0603_HandSoldering
R4: 24; R_0603_HandSoldering
R6: 100k; R_0603_HandSoldering

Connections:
/DIGIT0: IC1.2 (PB3(CLKI/ADC3/PCINT3)), Q1.1 (G)
/DIGIT1: IC1.3 (PB4(ADC2/PCINT4)), Q2.1 (G)
/DIGIT2: IC1.7 (PB2(SCK/ADC1/T0/PCINT2)), P1.3, Q3.1 (G)
/DIGIT3: IC1.5 (PB0(MOSI/AIN0/OC0A/PCINT0)), P1.4, Q4.1 (G)
/DIGIT4: IC1.6 (PB1(MISO/AIN1/OC0B/INT0/PCINT1)), P1.1, Q5.1 (G)
/~RESET: IC1.1 (PB5(~RESET~/ADC0/PCINT5/dW)), JP1.2, P1.5, R6.2
GND: BT1.2, C2.2, IC1.4 (GND), JP1.1, P1.6, Q1.2 (S), Q2.2 (S), Q3.2 (S), Q4.2 (S), Q5.2 (S)
unnamed: D1.1 (K), D2.1 (K), D3.1 (K), D4.1 (K), D5.1 (K), D6.1 (K), D7.1 (K), D8.1 (K), D9.1 (K), D10.1 (K), Q1.3 (D)
unnamed: D1.2 (A), D2.2 (A), D3.2 (A), D4.2 (A), D5.2 (A), D6.2 (A), D7.2 (A), D8.2 (A), D9.2 (A), D10.2 (A), R1.2
unnamed: D21.1 (K), D22.1 (K), D23.1 (K), D24.1 (K), D25.1 (K), D26.1 (K), D27.1 (K), D28.1 (K), D29.1 (K), D30.1 (K), D31.1 (K), D32.1 (K), Q2.3 (D)
unnamed: D21.2 (A), D22.2 (A), D23.2 (A), D24.2 (A), D25.2 (A), D26.2 (A), D27.2 (A), D28.2 (A), D29.2 (A), D30.2 (A), D31.2 (A), D32.2 (A), R2.2
unnamed: D41.1 (K), D42.1 (K), D43.1 (K), D44.1 (K), D45.1 (K), D46.1 (K), D47.1 (K), D48.1 (K), D49.1 (K), D50.1 (K), D51.1 (K), Q3.3 (D)
unnamed: D41.2 (A), D42.2 (A), D43.2 (A), D44.2 (A), D45.2 (A), D46.2 (A), D47.2 (A), D48.2 (A), D49.2 (A), D50.2 (A), D51.2 (A), R3.2
unnamed: D61.1 (K), D62.1 (K), D63.1 (K), D64.1 (K), D65.1 (K), Q4.3 (D)
unnamed: D61.2 (A), D62.2 (A), D63.2 (A), D64.2 (A), D65.2 (A), R4.2
unnamed: D81.1 (K), D82.1 (K), D83.1 (K), D84.1 (K), D85.1 (K), D86.1 (K), D87.1 (K), D88.1 (K), D89.1 (K), D90.1 (K), D91.1 (K), Q5.3 (D)
unnamed: D81.2 (A), D82.2 (A), D83.2 (A), D84.2 (A), D85.2 (A), D86.2 (A), D87.2 (A), D88.2 (A), D89.2 (A), D90.2 (A), D91.2 (A), R5.2
VCC: BT1.1, C2.1, IC1.8 (VCC), P1.2, R1.1, R2.1, R3.1, R4.1, R5.1, R6.1

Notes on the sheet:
Coincell battery holder CR2032

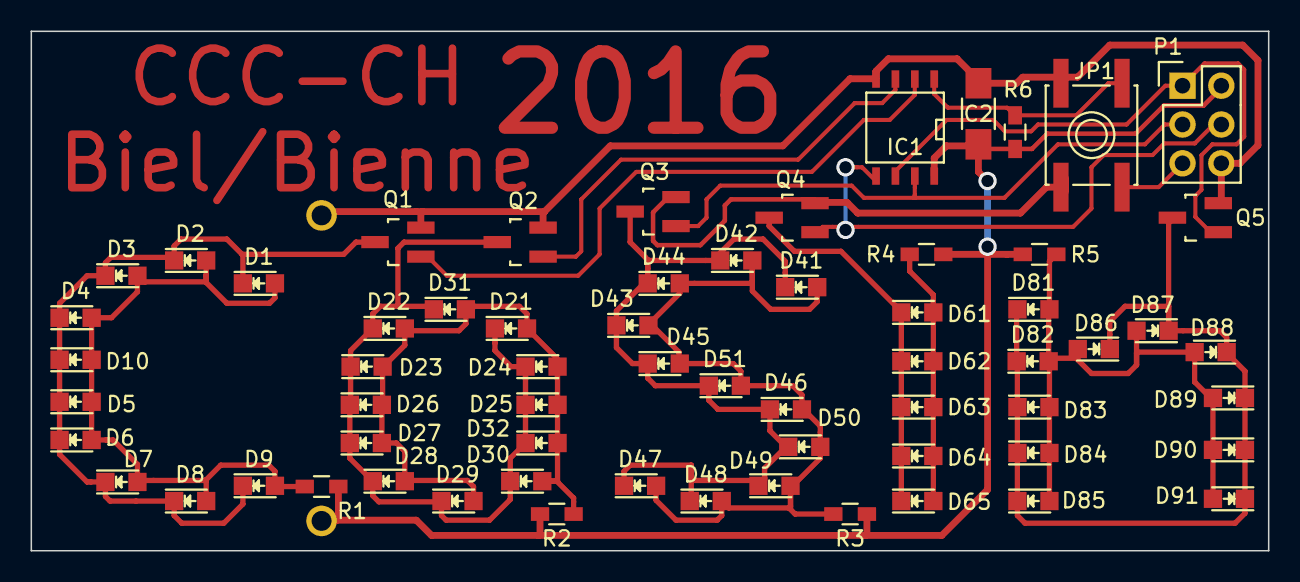
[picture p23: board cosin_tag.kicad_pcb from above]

Board: 2 copper layers, 81.0 x 34.0 mm, 65 parts (1 on the bottom side), 18 nets.

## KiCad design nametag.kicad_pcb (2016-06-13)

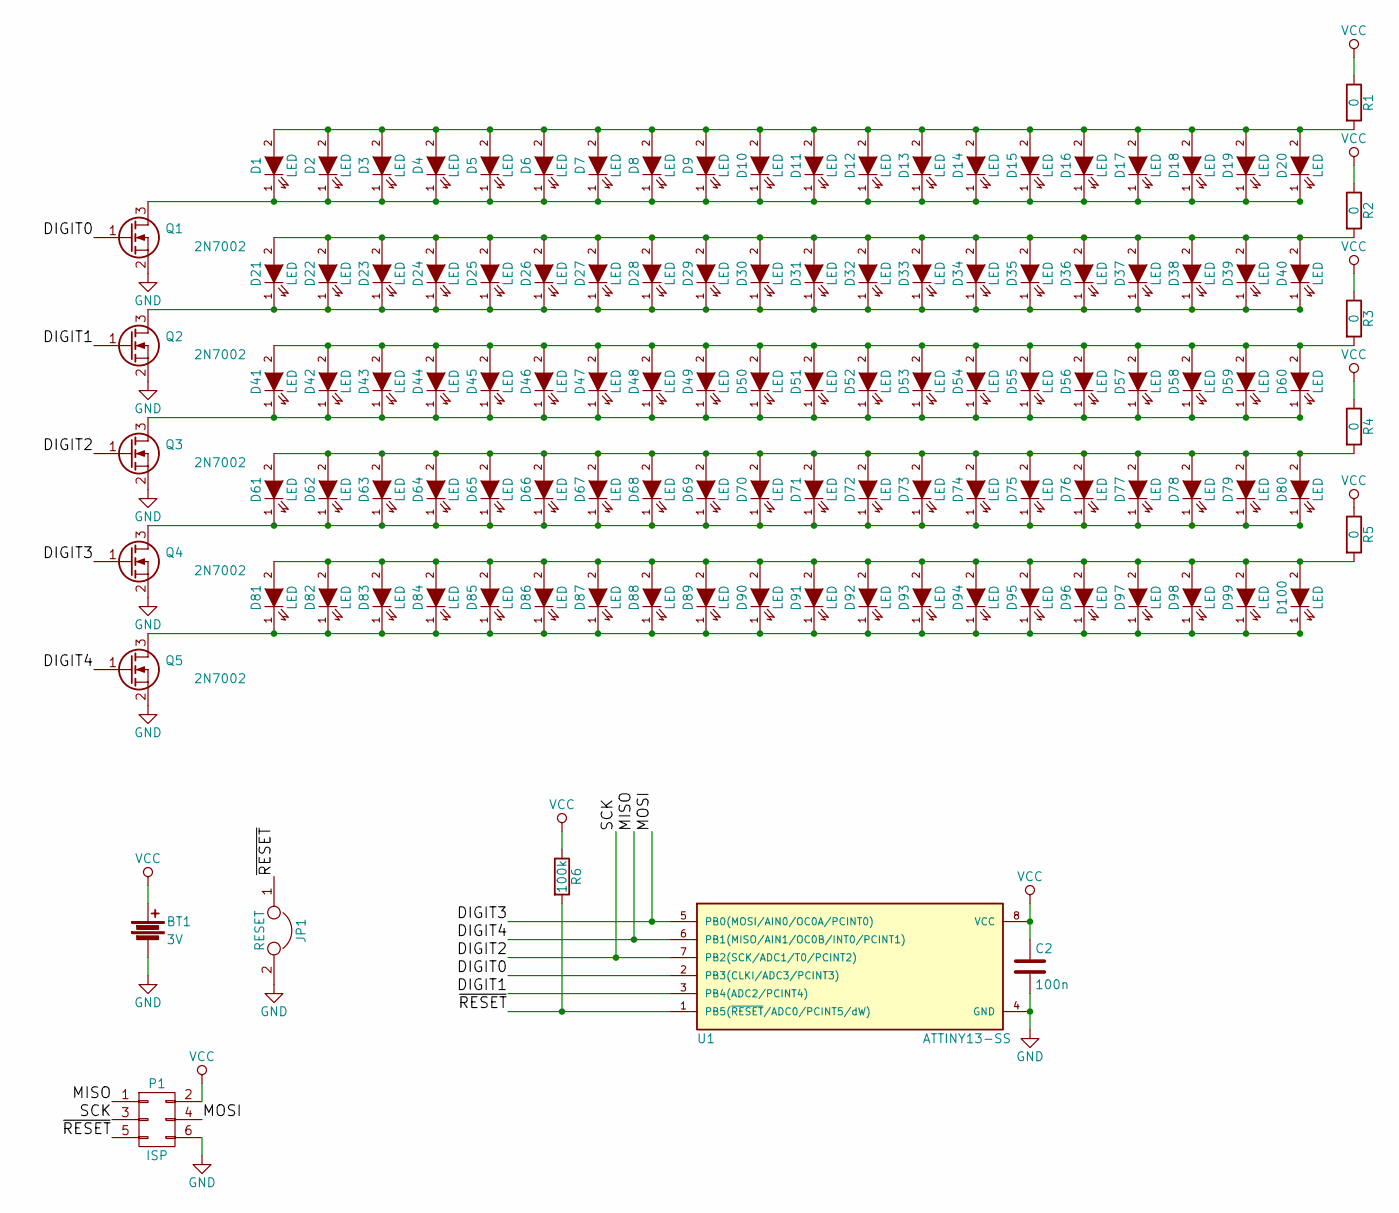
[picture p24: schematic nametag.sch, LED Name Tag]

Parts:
BT1: 3V; CR2032
C2: 100n; C_Disc_D3_P2.5
D1, D2, D3, D4, D5, D6, D7, D8, D9, D10, D11, D12, D13, D14, D15, D16, D17, D18, D19, D20, D21, D22, D23, D24, D25, D26, D27, D28, D29, D30, D31, D32, D33, D34, D35, D36, D37, D38, D39, D40, D41, D42, D43, D44, D45, D46, D47, D48, D49, D50, D51, D52, D53, D54, D55, D56, D57, D58, D59, D60, D61, D62, D63, D64, D65, D66, D67, D68, D69, D70, D71, D72, D73, D74, D75, D76, D77, D78, D79, D80, D81, D82, D83, D84, D85, D86, D87, D88, D89, D90, D91, D92, D93, D94, D95, D96, D97, D98, D99, D100: LED; LED-5MM
JP1: RESET; SW_PUSH_SMALL
P1: ISP; Pin_Header_Straight_2x03
Q1, Q2, Q3, Q4, Q5: 2N7002; SOT-23_Handsoldering
R1, R2, R3, R4, R5: 0; Resistor_Horizontal_RM10mm
R6: 100k; Resistor_Horizontal_RM10mm
U1: ATTINY13-SS; DIP-8_W7.62mm

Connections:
/DIGIT0: Q1.1 (G), U1.2 (PB3(CLKI/ADC3/PCINT3))
/DIGIT1: Q2.1 (G), U1.3 (PB4(ADC2/PCINT4))
/DIGIT2: P1.3, Q3.1 (G), U1.7 (PB2(SCK/ADC1/T0/PCINT2))
/DIGIT3: P1.4, Q4.1 (G), U1.5 (PB0(MOSI/AIN0/OC0A/PCINT0))
/DIGIT4: P1.1, Q5.1 (G), U1.6 (PB1(MISO/AIN1/OC0B/INT0/PCINT1))
/~RESET: JP1.1, P1.5, R6.2, U1.1 (PB5(~RESET~/ADC0/PCINT5/dW))
GND: BT1.2, C2.2, JP1.2, P1.6, Q1.2 (S), Q2.2 (S), Q3.2 (S), Q4.2 (S), Q5.2 (S), U1.4 (GND)
unnamed: D1.1 (K), D2.1 (K), D3.1 (K), D4.1 (K), D5.1 (K), D6.1 (K), D7.1 (K), D8.1 (K), D9.1 (K), D10.1 (K), D11.1 (K), D12.1 (K), D13.1 (K), D14.1 (K), D15.1 (K), D16.1 (K), D17.1 (K), D18.1 (K), D19.1 (K), D20.1 (K), Q1.3 (D)
unnamed: D1.2 (A), D2.2 (A), D3.2 (A), D4.2 (A), D5.2 (A), D6.2 (A), D7.2 (A), D8.2 (A), D9.2 (A), D10.2 (A), D11.2 (A), D12.2 (A), D13.2 (A), D14.2 (A), D15.2 (A), D16.2 (A), D17.2 (A), D18.2 (A), D19.2 (A), D20.2 (A), R1.2
unnamed: D21.1 (K), D22.1 (K), D23.1 (K), D24.1 (K), D25.1 (K), D26.1 (K), D27.1 (K), D28.1 (K), D29.1 (K), D30.1 (K), D31.1 (K), D32.1 (K), D33.1 (K), D34.1 (K), D35.1 (K), D36.1 (K), D37.1 (K), D38.1 (K), D39.1 (K), D40.1 (K), Q2.3 (D)
unnamed: D21.2 (A), D22.2 (A), D23.2 (A), D24.2 (A), D25.2 (A), D26.2 (A), D27.2 (A), D28.2 (A), D29.2 (A), D30.2 (A), D31.2 (A), D32.2 (A), D33.2 (A), D34.2 (A), D35.2 (A), D36.2 (A), D37.2 (A), D38.2 (A), D39.2 (A), D40.2 (A), R2.2
unnamed: D41.1 (K), D42.1 (K), D43.1 (K), D44.1 (K), D45.1 (K), D46.1 (K), D47.1 (K), D48.1 (K), D49.1 (K), D50.1 (K), D51.1 (K), D52.1 (K), D53.1 (K), D54.1 (K), D55.1 (K), D56.1 (K), D57.1 (K), D58.1 (K), D59.1 (K), D60.1 (K), Q3.3 (D)
unnamed: D41.2 (A), D42.2 (A), D43.2 (A), D44.2 (A), D45.2 (A), D46.2 (A), D47.2 (A), D48.2 (A), D49.2 (A), D50.2 (A), D51.2 (A), D52.2 (A), D53.2 (A), D54.2 (A), D55.2 (A), D56.2 (A), D57.2 (A), D58.2 (A), D59.2 (A), D60.2 (A), R3.2
unnamed: D61.1 (K), D62.1 (K), D63.1 (K), D64.1 (K), D65.1 (K), D66.1 (K), D67.1 (K), D68.1 (K), D69.1 (K), D70.1 (K), D71.1 (K), D72.1 (K), D73.1 (K), D74.1 (K), D75.1 (K), D76.1 (K), D77.1 (K), D78.1 (K), D79.1 (K), D80.1 (K), Q4.3 (D)
unnamed: D61.2 (A), D62.2 (A), D63.2 (A), D64.2 (A), D65.2 (A), D66.2 (A), D67.2 (A), D68.2 (A), D69.2 (A), D70.2 (A), D71.2 (A), D72.2 (A), D73.2 (A), D74.2 (A), D75.2 (A), D76.2 (A), D77.2 (A), D78.2 (A), D79.2 (A), D80.2 (A), R4.2
unnamed: D81.1 (K), D82.1 (K), D83.1 (K), D84.1 (K), D85.1 (K), D86.1 (K), D87.1 (K), D88.1 (K), D89.1 (K), D90.1 (K), D91.1 (K), D92.1 (K), D93.1 (K), D94.1 (K), D95.1 (K), D96.1 (K), D97.1 (K), D98.1 (K), D99.1 (K), D100.1 (K), Q5.3 (D)
unnamed: D81.2 (A), D82.2 (A), D83.2 (A), D84.2 (A), D85.2 (A), D86.2 (A), D87.2 (A), D88.2 (A), D89.2 (A), D90.2 (A), D91.2 (A), D92.2 (A), D93.2 (A), D94.2 (A), D95.2 (A), D96.2 (A), D97.2 (A), D98.2 (A), D99.2 (A), D100.2 (A), R5.2
VCC: BT1.1, C2.1, P1.2, R1.1, R2.1, R3.1, R4.1, R5.1, R6.1, U1.8 (VCC)

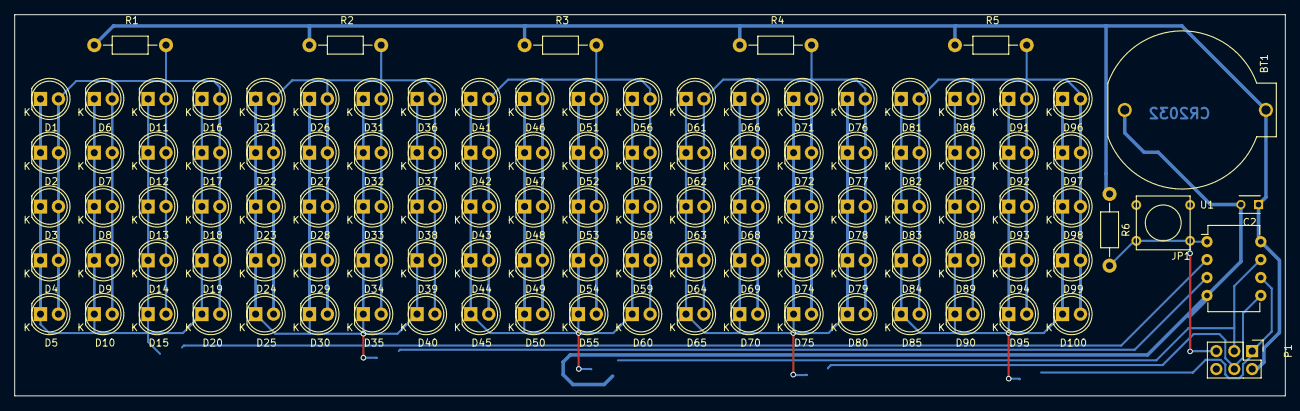
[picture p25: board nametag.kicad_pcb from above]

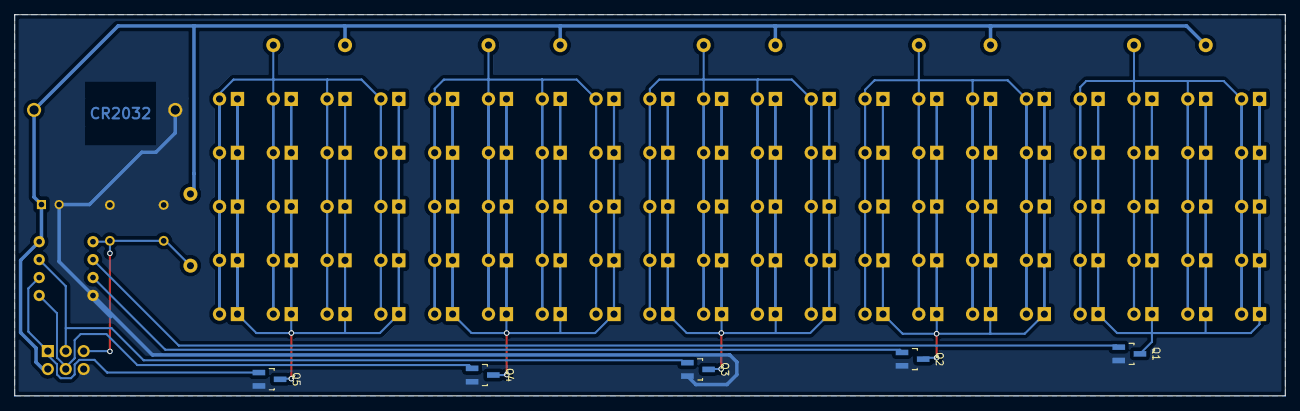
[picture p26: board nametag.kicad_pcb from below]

Board: 2 copper layers, 180.0 x 54.0 mm, 116 parts (5 on the bottom side), 18 nets.

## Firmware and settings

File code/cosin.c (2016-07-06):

/* 
 * cosin.c
 * 
 * CoSin 2016 LED Matrix Tag
 * Controller firmware
 * 
 * Copyright (c) 2016 Gregor Riepl <onitake@gmail.com>
 * 
 * This documentation describes Open Hardware and is licensed under the
 * CERN OHL v. 1.1.
 * You may redistribute and modify this documentation under the terms of the
 * CERN OHL v.1.1. (http://ohwr.org/cernohl). This documentation is distributed
 * WITHOUT ANY EXPRESS OR IMPLIED WARRANTY, INCLUDING OF
 * MERCHANTABILITY, SATISFACTORY QUALITY AND FITNESS FOR A
 * PARTICULAR PURPOSE. Please see the CERN OHL v.1.1 for applicable
 * conditions
*/

#include <avr/io.h>
#include <avr/interrupt.h>
#include <avr/pgmspace.h>
#include <util/delay.h>
#include <stdint.h>
#include <stdbool.h>
#include <string.h>
#include "map.h"

// Global state
struct {
	// The framebuffer
	// in column-major order
	uint8_t fb[8];
	// Current column
	uint8_t col;
	// Letter index
	uint8_t scene;
	// Horizontal offset
	uint8_t offset;
} global __attribute__((section(".noinit")));

const char MESSAGE[] PROGMEM = "COSIN 2016 ";
extern const unsigned char FONT_SANS8X8[][8] PROGMEM;
extern const unsigned char FONTMAP_SANS8X8[] PROGMEM;

// Initalize ports and timers
void init() {
	global.col = 0;
	memset(global.fb, 0, 8*8);
	global.scene = 0;
	global.offset = 0;

	PORTB &= ~0xff;
	DDRB |= 0xff;
	PORTD &= ~0x3f;
	DDRD |= 0x3f;
	PORTA &= ~0x03;
	DDRA |= 0x03;
	
	OCR1A = F_CPU / 1024 / 8;
	TIMSK |= _BV(TOIE1);
	// Fast PWM, TOP in OCR1A
	TCCR1A = _BV(WGM11) | _BV(WGM10);
	// CLKio / 1024
	TCCR1B = _BV(WGM13) | _BV(WGM12) | _BV(CS12) | _BV(CS10);
}

// Write a letter to the framebuffer
void wrletter(char letter, int8_t xoffset) {
	uint8_t xstart, xlen;
	if (xoffset < 0) {
		if (xoffset >= -8) {
			xstart = -xoffset;
			xlen = 8 + xoffset;
		} else {
			xstart = 0;
			xlen = 0;
		}
		xoffset = 0;
	} else if (xoffset >= 0) {
		if (xoffset < 8) {
			xlen = 8 - xoffset;
		} else {
			xlen = 0;
		}
		xstart = 0;
	}
	if (xlen > 0) {
		uint8_t index = pgm_read_byte(&FONTMAP_SANS8X8[(uint8_t) letter]);
		memcpy_P(global.fb + xoffset, FONT_SANS8X8[index] + xstart, xlen);
	}
}

// Refresh the display (one column at a time)
void refresh() {
	// Port map
	// COL1: PB1
	// COL2: PB3
	// COL3: PB5
	// COL4: PB7
	// COL5: PD5
	// COL6: PD3
	// COL7: PA0
	// COL8: PD1
	// ROW1: PB0
	// ROW2: PB2
	// ROW3: PB4
	// ROW4: PB6
	// ROW5: PD4
	// ROW6: PD2
	// ROW7: PA1
	// ROW8: PD0
	
	// Wiring
	// COL is driven by MOSFETs, while ROW is driven directly by MCU
	// Switch COL first, then present ROW bit pattern
	
	uint8_t bitmap = global.fb[global.col];
	uint8_t pa = 0, pb = 0, pd = 0;

	// switch is no good here - it will make avr-gcc allocate and
	// initialize 18 bytes of .data space for the lookup table - WTF!
	uint8_t col = global.col;
	if (col == 0) {
		pb |= _BV(1);
	} else if (col == 1) {
		pb |= _BV(3);
	} else if (col == 2) {
		pb |= _BV(5);
	} else if (col == 3) {
		pb |= _BV(7);
	} else if (col == 4) {
		pd |= _BV(5);
	} else if (col == 5) {
		pd |= _BV(3);
	} else if (col == 6) {
		pa |= _BV(0);
	} else if (col == 7) {
		pd |= _BV(1);
	}
	
	if (bitmap & _BV(0)) {
		pb |= _BV(0);
	}
	if (bitmap & _BV(1)) {
		pb |= _BV(2);
	}
	if (bitmap & _BV(2)) {
		pb |= _BV(4);
	}
	if (bitmap & _BV(3)) {
		pb |= _BV(6);
	}
	if (bitmap & _BV(4)) {
		pd |= _BV(4);
	}
	if (bitmap & _BV(5)) {
		pd |= _BV(2);
	}
	if (bitmap & _BV(6)) {
		pa |= _BV(1);
	}
	if (bitmap & _BV(7)) {
		pd |= _BV(0);
	}

	PORTA = pa;
	PORTB = pb;
	PORTD = pd;
	
	global.col = (global.col + 1) & 0x7;
}

// Update the display
ISR(TIMER1_OVF_vect) {
#if 0
	uint8_t col = global.scene >> 3;
	uint8_t row = global.scene & 0x07;
	uint8_t i;
	for (i = 0; i < 8; i++) {
		if (row == i) {
			global.fb[i] = 1 << col;
		} else {
			global.fb[i] = 0x00;
		}
	}
	global.scene = (global.scene + 1) & 0x3f;
#else
	wrletter(pgm_read_byte(&MESSAGE[global.scene]), -global.offset);
	uint8_t next;
	if (global.scene < sizeof(MESSAGE) - 2) {
		next = global.scene + 1;
	} else {
		next = 0;
	}
	wrletter(pgm_read_byte(&MESSAGE[next]), 8 - global.offset);
	if (global.offset >= 7) {
		global.scene = next;
		global.offset = 0;
	} else {
		global.offset++;
	}
#endif
}

int main() {
	init();
	
#if 1
	wrletter(pgm_read_byte(&MESSAGE[0]), 0);
	
	sei();
	
	while (true) {
		refresh();
	}
#else

	// COL1: PB7
	// COL2: PB5
	// COL3: PB3
	// COL4: PB1
	// COL5: PD5
	// COL6: PD3
	// COL7: PA0
	// COL8: PD1
	// ROW1: PB6
	// ROW2: PB4
	// ROW3: PB2
	// ROW4: PB0
	// ROW5: PD4
	// ROW6: PD2
	// ROW7: PA1
	// ROW8: PD0
	
	PORTB |= 0xff;
	PORTD |= 0x3f;
	PORTA |= 0x03;
	while (1);

	uint8_t pb = 0;
	uint8_t pd = 0;
	uint8_t pa = 0;
	
	while (1) {
		PORTB = pb;
		PORTD = pd;
		PORTA = pa;
		
		if (pb == 0xff) {
			if (pd == 0x3f) {
				if (pa == 0x3) {
					pa = 0;
				} else {
					pa++;
				}
			}
			pd++;
		}
		pb++;

		_delay_ms(10);
	}
	
#endif

	return 0;
}

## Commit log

2016-04-11 First version of example name tag board
    [nametag.kicad_pcb, nametag.sch]
2016-04-11 Added LED matrix example schema
    [matrixtag.kicad_pcb, matrixtag.sch]
2016-04-12 Added schematics and unrouted PCB of matrix display nametag
    [matrixtag.kicad_pcb, matrixtag.sch]
2016-04-23 Improved ground plane area
    [nametag.kicad_pcb]
2016-04-23 Moved parts to front layer
    [matrixtag.kicad_pcb]
2016-06-04 Fixed reset button rail mismatch Added missing traces (GND) Replaced reset button by 4-pin standard part
    [nametag.kicad_pcb, nametag.sch]
2016-06-04 Added SMD version of the nametag project using 0805 SMD LEDs.
    [nametag_smd.kicad_pcb, nametag_smd.sch]
2016-06-04 Added missing library components.
    Cleaned up a bit the area under the switch to make PCB production easier.
    [nametag_smd.kicad_pcb]
2016-06-08 Changed the package variant of the ATTINY13 to SO-8 narrow (ATTINY13-SS) because it is cheaper.
    Fixed wrong ISP pinning.
    Cleaned up the older thiner pcb tracks.
    [nametag_smd.kicad_pcb, nametag_smd.sch]
2016-06-10 Connected Vcc to ISP header Better GND routing in layout
    [nametag.kicad_pcb, nametag.sch]
2016-06-10 Added production outputs (needs update)
    [nametag-B.Cu.gbr, nametag-B.Mask.gbr, nametag-B.Paste.gbr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]
2016-06-11 Created a tag version for the CoSin conference 2016 in Biel/Bienne.
    [cosin_tag.kicad_pcb, cosin_tag.sch]
2016-06-11 Added schematic and pcb outputs as PDF for the nametag SMD and the cosin version.
2016-06-13 Added SMD battery holder footprint
2016-06-13 Moved SMD battery holder footprint to main library
2016-06-13 Added symbol and footprint for 2-color 8x8 matrix display
2016-06-13 THT nametag: Removed Vcc jumper wire
    [nametag.kicad_pcb]
2016-06-13 Finished matrix tag schematic and layout
    [matrixtag.kicad_pcb, matrixtag.sch]
2016-06-15 Minimized the areas in the layout where the tracks are close together. Made the tracks around the microcontroller smaller to improve yield when etching the PCB at home. For this a new netclass was in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
    Added the resistor values to the schematic.
    Updated all output files.
    [cosin_tag.kicad_pcb, cosin_tag.sch]
2016-06-21 Some small matrix tag updates
    [matrixtag.kicad_pcb]
2016-06-23 Fixed pinout of LED matrix footprint
2016-06-23 Fixed matrix tag layout with correct panel pinout
    [matrixtag.kicad_pcb, matrixtag.sch]
2016-06-23 Updated matrix tag schematic and PCB output
2016-06-23 Added Gerber files for matrix tag
    [matrixtag-B.Cu.gbr, matrixtag-B.Paste.gbr, matrixtag-B.SilkS.gbr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]
2016-06-30 Switched to new 8x8 font
2016-07-06 Fixed display of 0 terminator Increased banner speed
    [cosin.c]
